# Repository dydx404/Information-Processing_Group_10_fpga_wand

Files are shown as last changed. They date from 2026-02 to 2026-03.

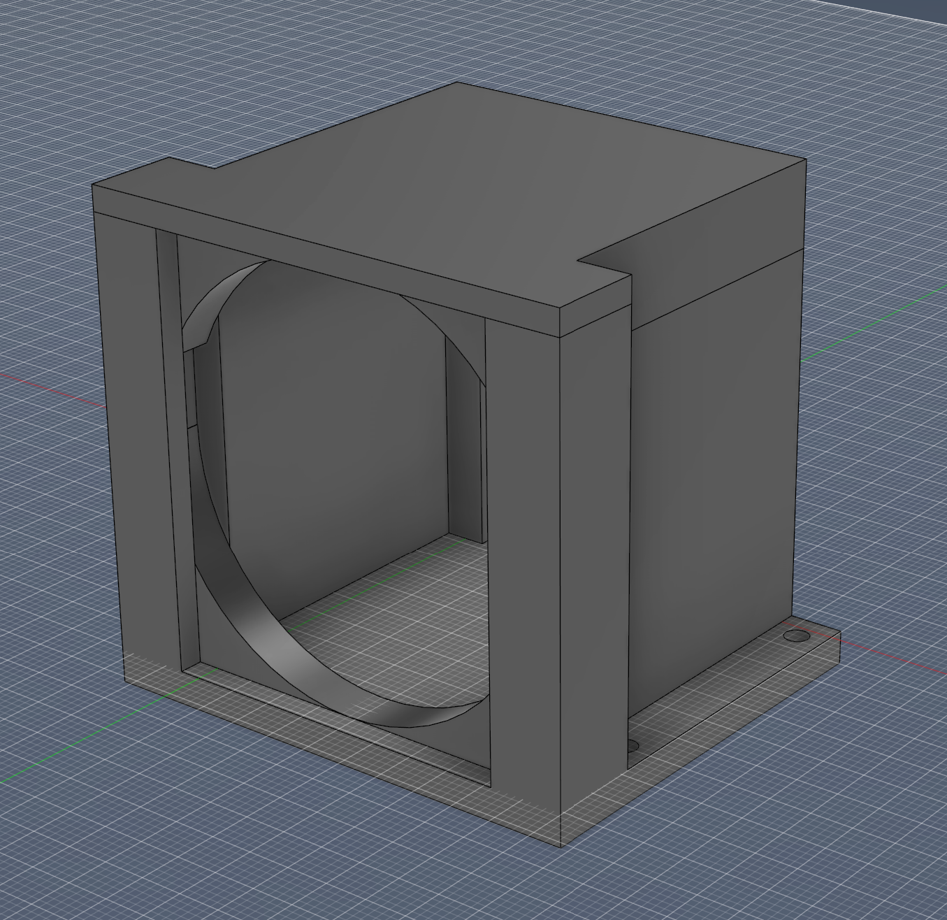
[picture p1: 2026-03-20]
hardware/camera/CamMount/Mount.png

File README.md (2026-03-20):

# FPGA-Wand

FPGA-Wand is a distributed drawing system: a bright LED wand is tracked by a
camera, reduced to centroid data on a PYNQ-Z1, streamed to a cloud service,
and turned into live drawings, scores, leaderboards, and node-control actions.

## Why This Project Is Interesting

This repository is best read as a compact embedded-systems portfolio piece. The
final system combines:

- FPGA + PS + cloud co-design in one working pipeline
- real-time point streaming over UDP
- bidirectional node control over HTTP
- multi-node operation against a shared backend
- live rendering, scoring, persistence, and leaderboards
- a browser-based control and observability console

## Start Here

If you are new to the repo, read these in order:

1. [docs/newcomer_guide.md](docs/newcomer_guide.md)
2. [docs/architecture/overview.md](docs/architecture/overview.md)
3. [FPGA/README.md](FPGA/README.md)
4. [software/README.md](software/README.md)

If you want a quick system explanation first, the project flow is:

```mermaid
flowchart LR
    W[LED Wand Tip] --> C[Camera]
    C --> PS[PYNQ PS Runtime]
    PS --> DMA[AXI DMA]
    DMA --> PL[Centroid PL IP]
    PL --> PS
    PS --> UDP[UDP Point Stream]
    UDP --> WB[Wand Brain on EC2]
    WB --> DB[(SQLite / Persistence)]
    WB --> UI[Live Web Console]
    UI --> HTTP[HTTP Control]
    HTTP --> PS
```

## Repo Map

The repository is organized around the three main implementation areas plus a
shared documentation tree:

- [hardware/](hardware/)
  physical build information for the wand and camera setup
- [FPGA/](FPGA/)
  the adopted PYNQ runtime plus FPGA design artefacts
- [software/](software/)
  the cloud service, protocol definitions, and software-side tools
- [docs/](docs/)
  architecture, validation, runbooks, and archival project notes

For newcomers focused on the technical system, the most important paths are
`FPGA/`, `software/`, and `docs/architecture/`. The `docs/group/` subtree is
kept for archival project-management and report-preparation purposes, but it is not
required to understand the final runtime design.

## Choose A Path

| If you want to understand... | Open this first | Then go here |
| --- | --- | --- |
| The whole system in 10 minutes | [docs/newcomer_guide.md](docs/newcomer_guide.md) | [docs/architecture/overview.md](docs/architecture/overview.md) |
| The FPGA and PYNQ path | [FPGA/README.md](FPGA/README.md) | [FPGA/runtime/ps_pl_flow.md](FPGA/runtime/ps_pl_flow.md) |
| The UDP protocol and point flow | [software/protocol/README.md](software/protocol/README.md) | [software/protocol/protocol/pynq-udp-flow.md](software/protocol/protocol/pynq-udp-flow.md) |
| The Wand Brain backend | [software/cloud/README.md](software/cloud/README.md) | [software/cloud/report/backend_system_report.md](software/cloud/report/backend_system_report.md) |
| The frontend and live console | [software/cloud/frontend/README.md](software/cloud/frontend/README.md) | [software/cloud/frontend/index.html](software/cloud/frontend/index.html) |
| The database model and persistence | [software/cloud/database/README.md](software/cloud/database/README.md) | [software/cloud/database/models.py](software/cloud/database/models.py) |
| How to run the final system | [docs/demo/final_runbook.md](docs/demo/final_runbook.md) | [software/tools/README.md](software/tools/README.md) |
| Validation evidence | [docs/testing/system_validation_report.md](docs/testing/system_validation_report.md) | [software/tools/README.md](software/tools/README.md) |

## What The Final System Does

The final presented system follows this path:

1. A camera observes a bright LED wand tip.
2. The PYNQ PS preprocesses the frame into a binary image.
3. AXI DMA streams the image into a custom centroid IP in the PL.
4. The PS reads centroid statistics, filters them, and maintains stroke logic.
5. The PS sends accepted points to Wand Brain over UDP.
6. Wand Brain reconstructs attempts, renders images, scores them, stores
   finalized results, and serves the live dashboard.
7. The dashboard can also send HTTP control messages back to the PYNQ node.

The architecture deliberately separates:

- UDP as the low-latency point-stream data plane
- HTTP as the control and dashboard plane

## Engineering Highlights

- **Narrow, stable PL design**
  The adopted FPGA path uses a compact centroid-reduction IP rather than a
  heavier full-image pipeline, keeping the PL focused on deterministic
  acceleration.
- **Policy in the PS**
  The PYNQ PS handles filtering, stroke state, node control, and networking, so
  behaviour can be tuned without reworking the PL.
- **Stateful cloud runtime**
  Wand Brain reconstructs live attempts in memory, finalizes them into
  renderable images, scores them, and persists results only when appropriate.
- **Separation of planes**
  UDP is reserved for the point-stream path, while HTTP handles control,
  dashboard status, and operator-facing behaviour.
- **Operator-friendly system**
  The final web console supports monitoring, template selection, node control,
  recent attempts, stroke timing, and leaderboards from one page.

## Local Development

### Run the cloud app

```bash
cd software/cloud
bash start_script.sh --install-deps
```

Then open:

```text
http://127.0.0.1:8000/
```

### Run the PYNQ sender

The board-side demo is:

- [FPGA/runtime/pynq_wand_brain_demo.py](FPGA/runtime/pynq_wand_brain_demo.py)

The main demo can use the configured EC2 address or an overridden
`BRAIN_HOST` value. Each board also needs its own:

- `DEVICE_NUMBER`
- `WAND_ID`

For a more complete run path, see:

- [docs/demo/final_runbook.md](docs/demo/final_runbook.md)

## Source Of Truth

This repo contains both **canonical source** and **runtime-generated data**.
For newcomers, the key distinction is:

- edit and read the source under `hardware/`, `FPGA/`, `software/`, and `docs/`
- do not treat runtime-generated files as the authoritative implementation

Runtime-generated files are intentionally not the source of truth for GitHub:

- `software/cloud/data/fpgawand.sqlite3`
- `software/cloud/data/node_control_state.json`
- `software/cloud/data/outputs/*.png`
- EC2 deployment-only copies such as `cloud/alt_live_console`

The authoritative template source images live in:

- [software/cloud/backend/versions/brain_v2_scoring/data/templates](software/cloud/backend/versions/brain_v2_scoring/data/templates)

## Notes For Contributors

Commit the canonical source under `hardware/`, `FPGA/`, `software/`, and
`docs/`. Avoid committing runtime-only data copied back from local runs or EC2.

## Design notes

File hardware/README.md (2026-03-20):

# Hardware

This directory contains the physical build-side documentation for the project.

## What To Expect Here

This subtree is intentionally lighter than `FPGA/` and `software/`, because the
main engineering depth of the final system sits in the node runtime and cloud
service. Use `hardware/` for physical context:

- what the wand looked like
- how the camera was positioned
- how the physical setup supported reliable tracking

## Subsystems

- [wand/](wand/)
  the physical wand implementation used by the final system.
- [camera/](camera/)
  camera-side mounting, placement, and sensing notes.

## Relationship To The Rest Of The Repo

- [FPGA/](../FPGA/)
  contains the programmable-logic design artefacts and PYNQ runtime code.
- [software/](../software/)
  contains the EC2 cloud service, protocols, and software-side tools.

Use this folder to present what was physically built, rather than the code that
ran on top of it.

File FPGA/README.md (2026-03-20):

# FPGA

This directory contains the FPGA-side implementation of the project.

## If You Open One File First

For most newcomers, start with:

- [runtime/ps_pl_flow.md](runtime/ps_pl_flow.md)

That document explains the final adopted PS/PL signal flow and points back to
the relevant runtime code and Vivado artefacts.

## Main Areas

- [runtime/](runtime/)
  PYNQ-side Python runtime used to bridge the camera/centroid pipeline to the
  Wand Brain cloud service.
- [designs/](designs/)
  archived hardware design artefacts, including the version used in the final
  system and fallback versions.

## PS / PL Architecture

The deployed board design is best understood as a split between:

- the PS as the runtime controller
- the PL as a centroid-statistics accelerator

At a high level, the signal flow is:

1. the PS captures a camera frame
2. the PS preprocesses it into a binary `640 x 480` image
3. the PS sends that image through AXI DMA into the custom centroid IP
4. the PL reduces the frame into `sum_x`, `sum_y`, `count`, `frame_id`, and
   `valid`
5. the PS reads those registers, computes the centroid, applies filtering and
   stroke logic, and sends accepted points to Wand Brain

The control flow is also PS-led:

- the PS polls node control over HTTP
- applies immediate or next-stroke configuration changes
- decides whether tracking is enabled
- decides whether a centroid is good enough to sketch or transmit
- manages the UDP stroke state machine through the runtime bridge

So the PL is intentionally narrow and stable, while the PS holds the policy,
integration, and live control behavior.

For the detailed step-by-step version, see
[runtime/ps_pl_flow.md](runtime/ps_pl_flow.md).

## Newcomer Route

If you are trying to understand the FPGA contribution quickly, read in this
order:

1. [runtime/ps_pl_flow.md](runtime/ps_pl_flow.md)
2. [runtime/pynq_wand_brain_demo.py](runtime/pynq_wand_brain_demo.py)
3. [runtime/pynq_udp_bridge.py](runtime/pynq_udp_bridge.py)
4. [designs/centroid_pipeline/used_version/README.md](designs/centroid_pipeline/used_version/README.md)
5. [designs/centroid_pipeline/used_version/source/frame_centroid.v](designs/centroid_pipeline/used_version/source/frame_centroid.v)

## Suggested Tour

Start here if you want to present the FPGA contribution clearly:

1. [runtime/pynq_wand_brain_demo.py](runtime/pynq_wand_brain_demo.py)
2. [runtime/pynq_udp_bridge.py](runtime/pynq_udp_bridge.py)
3. [runtime/ps_pl_flow.md](runtime/ps_pl_flow.md)
4. [designs/README.md](designs/README.md)
5. [designs/centroid_pipeline/used_version/README.md](designs/centroid_pipeline/used_version/README.md)

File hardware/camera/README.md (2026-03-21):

# Camera Hardware

This folder documents the camera-side hardware used in the FPGA wand tracking
setup. It covers the selected image sensor, lens characteristics, IR filtering
approach, and the mechanical mounting work used to support the sensing node.

## Purpose

The camera subsystem is responsible for reliably observing the tracked wand tip
under motion. The hardware choice emphasizes:

- fast image capture
- reduced motion distortion
- compatibility with IR-assisted tracking
- practical integration with the `PYNQ-Z1`-based node

## Selected Camera

The camera used for the project is the `Arducam B0332`, based on the `OV9281`
global shutter image sensor.

Relevant supporting files in this folder include:

- `B0332_OV9281_Global_Shutter_UVC_Camera_Datasheet.pdf`
- `CamMount/Design_Notes.md`
- the CAD and render files under `CamMount/`

## Sensor Characteristics

Key parameters of the selected camera are:

- `OV9281` monochrome sensor
- global shutter
- `1280 x 800` resolution
- `1 MP` image size
- `3 um x 3 um` pixel size
- `1/4 inch` optical format
- `68 dB` dynamic range
- UVC output support
- `MJPG` and `YUY2` output formats

## Frame Rate

Documented operating modes include:

- `100 fps` at `1280 x 800` in `MJPG`
- `10 fps` at `1280 x 800` in `YUY2`

For this project, the high frame rate is important because fast wand motion
should not be limited by camera capture speed.

## Why This Camera Was Chosen

This camera appears to have been selected for three main reasons:

- `Global shutter` reduces rolling-shutter distortion when the wand moves
  quickly.
- `High frame rate` supports motion tracking with less temporal blur and better
  responsiveness.
- `Monochrome + IR sensitivity` makes the sensor suitable for filtered or
  IR-assisted optical tracking.

Together, these characteristics make the camera a good fit for a tracking
system rather than a general-purpose imaging application.

## Optics And Lens

The current notes indicate the following lens characteristics:

- `2.8 mm` effective focal length
- approximately `70 deg` horizontal field of view
- distortion below `1%`
- `M12 x P0.5 mm` lens mount

This combination suggests a compact wide-angle configuration suitable for
watching the wand workspace from a fixed camera position.

## IR Sensitivity And Filtering

The camera is noted as having no IR cut filter, which means it is sensitive to
near-infrared light. That makes it suitable for use with IR illumination or IR
pass filtering.

This is useful for the project because:

- the tracked target can remain bright in the IR band
- background visible-light clutter can be reduced
- tracking can be made more robust under mixed lighting conditions

The camera mount work in `CamMount/` is intended to hold the IR filter in front
of the lens while minimizing visible light leakage.

## IR Filter Note

The current filter notes record:

- aperture: `49 mm`
- pass band: `85 nm`

These values should be confirmed and expanded later with the exact center
wavelength, supplier part number, and mounting dimensions.

## Mechanical Integration

Mechanical support for the camera is documented in the `CamMount/` folder,
including CAD files and design notes. The mount work appears to focus on:

- placing the filter securely in front of the camera
- reducing stray visible light
- keeping the assembly easy to build and service

This indicates the sensing setup was designed as a real prototype assembly, not
just a camera selection on paper.

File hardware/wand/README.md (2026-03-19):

# Wand Hardware

This folder groups the physical wand implementations and related notes.

## Current Layout

- [current_led_wand/](current_led_wand/)
  the final physical wand direction used for the project demo.

The final integrated system used a simple 3D-printed LED wand as the tracked
optical target.

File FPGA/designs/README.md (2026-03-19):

# FPGA Design Archive

This folder is for the hardware-design side of the PYNQ / FPGA subsystem.

It is intentionally separate from the Python notebook/runtime files in
[../](../) so the repo can present:

- the design currently used in the live system
- a fallback version of that design
- space for a teammate's alternative design work

## Layout

- [centroid_pipeline/](centroid_pipeline/)
  current centroid-based design family used by the live system.
- [teammate_design/](teammate_design/)
  reserved slot for a second design track.

## Per-Version Conventions

Each version folder is split into:

- `source/`
  HDL, block-design Tcl, IP configuration exports, or any source artefacts
  needed to recreate the design.
- `constraints/`
  XDC constraints and board-specific pin/timing files.
- `export/`
  generated handoff artefacts you intentionally want to keep, such as `.bit`,
  `.hwh`, `.xsa`, or packaged deliverables.
- `docs/`
  design notes, architecture summaries, and implementation rationale.
- `reports/`
  timing, utilization, and synthesis/implementation reports worth preserving.
- `images/`
  screenshots, block diagrams, or presentation visuals.

## Suggested Usage

- Put the design you actually demonstrated into `centroid_pipeline/used_version`.
- Put the simpler or safer backup build into `centroid_pipeline/fallback_version`.
- Let your teammate populate `teammate_design/` with another architecture or
  implementation approach.

If you later want more specific names, you can rename these top-level design
folders without changing the rest of the structure.

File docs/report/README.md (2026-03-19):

# Report Notes

This folder is reserved for report-specific material that is separate from the
runtime code and operator documentation.

For the actual system architecture and interfaces, prefer:

- [../architecture/overview.md](../architecture/overview.md)
- [../../README.md](../../README.md)

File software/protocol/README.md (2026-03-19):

# Protocols

This directory contains the explicit interface contracts used across the
project.

## Current Important Specs

- [protocol/pynq-udp-brian-v1.md](protocol/pynq-udp-brian-v1.md)
  defines the fixed-size UDP point-stream packet from PYNQ to Wand Brain.
- [protocol/pynq-udp-flow.md](protocol/pynq-udp-flow.md)
  explains how the PYNQ sender, UDP receiver, parser, and backend state machine
  use that packet format end to end.
- [protocol/brain-web_api.md](protocol/brain-web_api.md)
  indexes the HTTP API families used by the frontend, control plane, scoring,
  leaderboard, and database views.
- [protocol/brain_api/README.md](protocol/brain_api/README.md)
  expands the Brain HTTP APIs into separate detailed guides by feature area.

## Design Principle

The protocol docs are the contract boundary between subsystems. The packet
format should remain stable unless all affected owners agree to the change.

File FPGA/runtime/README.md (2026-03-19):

# PYNQ Runtime

Use [pynq_udp_bridge.py](pynq_udp_bridge.py) to send centroid points from a
PYNQ notebook or script to Wand Brain.

## Repository Layout

- runtime integration code stays directly in [./](.)
- hardware design artefacts live under [../designs/](../designs/)

That split keeps the repo easier to present:

- software/runtime logic in one place
- Vivado/export/design evidence in another

## What It Does

- keeps the camera + DMA + MMIO centroid pipeline unchanged
- performs an HTTP preflight check against Wand Brain
- sends one `wb-point-v1` UDP packet per valid centroid point
- starts a new stroke on the first valid point after idle
- sends one explicit `STROKE_END` packet after a short no-blob gap

## Deep Dive

For the actual deployed signal path and control decisions, see
[ps_pl_flow.md](ps_pl_flow.md). That document walks through:

- camera frame preprocessing on the PS
- DMA transfer into the custom centroid IP
- register readback from the PL
- fresh-result detection using `frame_id`
- UDP stroke generation
- server-driven node control and acknowledgements

## Minimal Notebook Pattern

```python
import sys
sys.path.append("/home/xilinx/Information-Processing_Group_10_fpga_wand")

from FPGA.runtime.pynq_udp_bridge import WandBrainConfig, WandBrainUdpBridge

bridge = WandBrainUdpBridge(
    WandBrainConfig(
        brain_host="13.51.156.87",
        brain_udp_port=41000,
        brain_api_port=8000,
        device_number=1,
        wand_id=1,
        starting_stroke_id=1,
        gap_timeout_ms=220,
        mirror_x=True,
    )
)

print(bridge.preflight_check())
```

## Notes

- Set `brain_host` to the current EC2 public IP. In the main demo script this
  can be overridden with the `BRAIN_HOST` environment variable.
- `timestamp_ms=None` means the bridge uses local monotonic milliseconds.
- `mirror_x=True` makes backend rendering match the mirrored local sketch view.
- The bridge sends explicit `STROKE_END`, which is compatible with both older
  and newer Wand Brain builds.
- For the centroid notebook demo, prefer `MIN_COUNT_TO_ACCEPT >= 4` and
  `VALID_STREAK_REQUIRED >= 2` to suppress single-pixel flicker and one-frame
  false starts.

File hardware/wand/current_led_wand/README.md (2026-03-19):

# Current LED Wand

This folder is reserved for the final wand hardware that was actually used in
the project demonstration.

Recommended contents:

- photos of the 3D-printed wand
- LED placement notes
- simple wiring notes
- any assembly drawings or STL references
- practical observations from testing

Important context:

- this final wand was used as a simple bright tracked tip for the
  camera/FPGA pipeline
- the repo’s active implementation does not require a separate embedded wand
  firmware path

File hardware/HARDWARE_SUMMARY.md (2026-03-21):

# Hardware Report

## 1. Introduction

This report summarizes the hardware work documented under
`fpga_wand/hardware/`. The purpose of this part of the repository is to record
the physical prototype used in the FPGA wand tracking system, including the
camera subsystem, the tracked wand, the node-level hardware arrangement, and
the supporting bill of materials.

The contents of this folder show that the project progressed beyond algorithm
and FPGA development into a working physical prototype with selected hardware,
custom mechanical parts, and a defined sensing configuration.

## 2. Hardware System Overview

The documented hardware is centered on a `PYNQ-Z1`-based node used for image
capture and system integration. At the top level, the hardware folder includes
general notes and a node layout diagram that describe how the main components
fit together.

The single-node layout indicates the following structure:

- a camera connected through a USB hub
- a WiFi adapter connected through the same USB hub
- the hub connected to the `PYNQ-Z1`
- the `PYNQ-Z1` connected to a host computer for power and Ethernet

This arrangement suggests a practical prototype architecture in which the FPGA
board acts as the central processing node while the camera and communications
hardware are attached as external peripherals.

## 3. Camera Subsystem

The camera subsystem is the most fully documented part of the hardware
directory. The current records identify the selected camera as the `Arducam
B0332`, based on the `OV9281` image sensor.

The documented sensor characteristics include:

- monochrome operation
- global shutter imaging
- `1280 x 800` resolution
- `1 MP` image size
- support for `MJPG` and `YUY2` output
- high-speed operation up to `100 fps` in `MJPG`

The camera choice appears to have been driven by the needs of fast optical
tracking. In particular, the use of a global shutter reduces image distortion
during rapid wand motion, while the high frame rate helps ensure that the
camera is not the main bottleneck in the tracking pipeline.

The optics notes further indicate a `2.8 mm` lens with an approximately
`70 deg` horizontal field of view and an `M12 x P0.5 mm` lens mount. The camera
is also described as having no IR cut filter, making it suitable for
near-infrared-sensitive operation.

Taken together, these details show that the selected camera was well matched to
the requirements of a motion-tracking system rather than a general-purpose
imaging task.

## 4. IR Filtering And Camera Mount Design

The repository contains dedicated camera mount assets under
`hardware/camera/CamMount/`, including CAD files, a rendered image, and a set
of design notes. These files provide strong evidence that the optical setup was
mechanically developed rather than left as a loose concept.

The documented design intent of the mount is to:

- position the IR filter directly in front of the camera
- reduce visible light leakage into the optical path
- keep the assembly easy to install, remove, and adjust
- support repeatable positioning during prototype testing

This mount design is important because the effectiveness of IR-assisted
tracking depends not only on the sensor itself, but also on how well the filter
is integrated into the physical camera assembly. The available documentation
shows that the project considered both optical performance and practical
assembly during this stage of development.

## 5. Wand Hardware

The hardware folder also documents the tracked wand used in the final project
direction. The available files include a wand model, a rendered image, and a
simple schematic.

These materials indicate that the final tracked target was a custom handheld
LED wand rather than a complex embedded device. The wand appears to include:

- a long narrow visible structure suitable for tracking
- a custom enclosure
- a pushbutton integrated into the handle
- a simple electrical arrangement using a `7.4V` supply, a red LED, and an IR
  LED

This suggests that the wand was intended to act as a bright and easily detected
optical target for the camera/FPGA pipeline, while keeping the hardware simple
and practical for demonstration purposes.

## 6. Bill Of Materials

The top-level bill of materials provides a first-pass procurement view of the
system. It includes the major camera, compute, optical, power, and enclosure
items needed to assemble the prototype.

The BOM covers:

- cameras and lenses
- USB and connectivity hardware
- `PYNQ-Z1` boards
- WiFi adapters
- LEDs and switches
- battery-related items
- custom 3D-printed mechanical parts

This is a useful foundation for prototype assembly, although it still reads as
a draft document rather than a fully finalized production BOM. Some entries are
generic, some are marked as optional, and a few text encoding issues remain in
the file.

## 7. Assessment Of Current Progress

Based on the files currently present in `hardware/`, the core hardware concept
for the project has already been established. The repository shows evidence of:

- camera selection based on tracking requirements
- definition of the node-level hardware arrangement
- mechanical design work for camera filtering and mounting
- development of a dedicated tracked wand form factor
- preparation of a bill of materials for the build

This means the hardware portion of the project is already beyond the idea stage.
The available documentation points to a real prototype effort with concrete
design decisions and supporting artifacts.

## 8. Remaining Gaps

Although the main hardware direction is clearly documented, the folder still
has some areas that would benefit from further reporting and cleanup.

The most obvious remaining gaps are:

- finalized supplier-ready BOM entries
- clearer assembly instructions
- dimensions and tolerances for the printed parts
- print settings and recommended materials
- fuller wand-side written documentation
- photos of the assembled prototype
- final placement, calibration, and validation notes for the camera setup

These are primarily documentation and refinement tasks rather than missing
fundamental hardware design work.

## 9. Conclusion

The `fpga_wand/hardware/` subtree documents a credible physical prototype for
the FPGA wand tracking project. The strongest elements are the selected global
shutter camera, the IR-aware camera mount design, the custom LED wand model,
and the single-node architecture built around the `PYNQ-Z1`.

In summary, the repository already captures the essential hardware design of the
system. The main next step is to improve completeness and presentation by
expanding assembly details, cleaning the BOM, and recording more evidence from
the final physical build.

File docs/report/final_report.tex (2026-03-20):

\documentclass[10pt,a4paper]{article}

\usepackage[margin=1.6cm]{geometry}
\usepackage[T1]{fontenc}
\usepackage[utf8]{inputenc}
\usepackage{lmodern}
\usepackage{microtype}
\usepackage{graphicx}
\usepackage{booktabs}
\usepackage{tabularx}
\usepackage{array}
\usepackage{enumitem}
\usepackage{xcolor}
\usepackage{hyperref}
\usepackage{tikz}
\usetikzlibrary{arrows.meta,positioning,shapes.geometric}

\hypersetup{
  colorlinks=true,
  linkcolor=black,
  urlcolor=blue!50!black
}

\setlength{\parindent}{0pt}
\setlength{\parskip}{0.45em}
\setlist[itemize]{leftmargin=*, itemsep=0.2em, topsep=0.2em}
\setlist[enumerate]{leftmargin=*, itemsep=0.2em, topsep=0.2em}

\title{\vspace{-1.2em}\textbf{FPGA Wand: A Multi-Node Interactive Drawing System with Local FPGA Processing and Cloud Coordination}\vspace{-0.8em}}
\author{[Author Name]}
\date{}

\begin{document}
\maketitle
\vspace{-1.4em}

\section{Purpose of the System}

The aim of this project was to build a distributed interactive system in which
multiple FPGA SoC nodes perform meaningful local processing, exchange compact
events with a cloud service, and can also be influenced by server-side control.
The final implemented system is an interactive ``wand drawing'' platform built
around PYNQ boards, a camera-based local processing pipeline, and a cloud
service called \emph{Wand Brain}. Each node observes a bright LED wand through a
camera, reduces each frame locally to a centroid-like point, and transmits this
point stream to the cloud as stroke events. The cloud reconstructs attempts,
renders them live in a browser dashboard, scores finalized strokes against
target templates, maintains leaderboards, and sends control settings back to
the nodes.

This final system was chosen because it satisfies all minimum functional
requirements while remaining technically rich. It demonstrates local processing
on the FPGA SoC device, server-side event processing, bidirectional
communication between node and server, and concurrent operation of at least two
nodes. The design also leaves clear space for extension, including alternative
templates, richer scoring, and more advanced node-side vision.

\section{Overall Architecture}

\begin{figure}[t]
\centering
\begin{tikzpicture}[
  node distance=0.85cm and 0.65cm,
  box/.style={draw, rounded corners, align=center, minimum width=2.4cm, minimum height=0.9cm, fill=blue!4},
  smallbox/.style={draw, rounded corners, align=center, minimum width=2.15cm, minimum height=0.8cm, fill=green!4},
  cloudbox/.style={draw, rounded corners, align=center, minimum width=2.65cm, minimum height=0.95cm, fill=orange!6},
  line/.style={-{Latex[length=2mm]}, thick}
]
\node[box] (camera) {USB Camera\\BGR Frames};
\node[box, right=of camera] (ps) {PYNQ PS\\OpenCV preprocessing\\UDP/HTTP logic};
\node[smallbox, below=of ps] (dma) {AXI DMA};
\node[smallbox, left=of dma] (pl) {Custom PL IP\\frame\_centroid\_axi};
\node[cloudbox, right=of ps, xshift=1.0cm] (brain) {EC2 ``Wand Brain''\\UDP ingest, render, score, persist};
\node[cloudbox, below=of brain] (db) {SQLite history\\leaderboards};
\node[box, above=of brain] (web) {Browser dashboard\\live view and control};

\draw[line] (camera) -- node[above, font=\scriptsize] {frame capture} (ps);
\draw[line] (ps) -- node[right, font=\scriptsize] {binary frame buffer} (dma);
\draw[line] (dma) -- node[below, font=\scriptsize] {AXI stream} (pl);
\draw[line] (pl) -- node[left, font=\scriptsize] {AXI-Lite stats} (ps);
\draw[line] (ps) -- node[above, font=\scriptsize] {24-byte UDP point packets} (brain);
\draw[line] (brain) -- node[right, font=\scriptsize] {finalized attempts} (db);
\draw[line] (web) -- node[right, font=\scriptsize] {HTTP polling} (brain);
\draw[line] (brain.west) to[bend right=18] node[below, font=\scriptsize] {HTTP node control} (ps.east);
\end{tikzpicture}
\caption{End-to-end architecture of the final system. The fast data plane uses
UDP point events from the node to the cloud, while the control plane uses HTTP
from the cloud back to the node.}
\label{fig:system-architecture}
\end{figure}

Figure~\ref{fig:system-architecture} shows the split between the local node and
the cloud service. The local node combines the programmable logic (PL) and the
processing system (PS) of the PYNQ board. The PS is responsible for camera
capture, grayscale conversion, resizing to $640 \times 480$, thresholding,
runtime filtering, stroke management, and networking. The PL accelerates the
repetitive per-pixel reduction stage by scanning the thresholded binary frame
and exposing compact image statistics instead of a full processed image.

\subsection*{Node-side PS/PL partition}

The adopted FPGA design consists of a custom AXI-stream IP,
\texttt{frame\_centroid\_axi}, attached to an AXI DMA engine and accessed by the
PS through AXI-Lite. After the PS thresholds a frame, it writes the binary
image into a DMA buffer in memory. The DMA then streams the image into the PL,
where four pixels are processed per 32-bit beat. The custom IP accumulates:
\begin{itemize}
  \item the horizontal coordinate sum $\sum x$,
  \item the vertical coordinate sum $\sum y$,
  \item the foreground-pixel count,
  \item a frame identifier, and
  \item a valid bit.
\end{itemize}
The PS reads these registers through MMIO and computes the centroid using
$c_x=\sum x / \mathrm{count}$ and $c_y=\sum y / \mathrm{count}$. This is a
deliberate partition: the PL performs the regular streaming arithmetic, while
the PS keeps the flexible logic in software, including filtering, control
handling, sketch rendering, and networking.

\subsection*{Cloud-side runtime}

The cloud service is a FastAPI application deployed on EC2. It is divided into
two layers. The base runtime receives UDP packets on port 41000, validates and
parses them into structured point events, groups them into live attempts, and
renders both live and finalized drawings. A wrapper layer adds persistence,
template selection, node control, recent-attempt views, leaderboards, and the
HTML dashboard. The server also exposes health, template, and debugging routes
over HTTP on port 8000.

The browser frontend is a deliberately simple single-page console. It polls the
backend rather than using WebSockets, which made the system easier to debug and
deploy during rapid iteration. Live frame polling is configured at 180\,ms,
selected-wand status at 500\,ms, and health/leaderboard polling at slower
intervals. This produces a responsive operator view while keeping the client
logic lightweight.

\section{Performance Metrics and Their Rationale}

Because the project is an interactive distributed system, its performance
cannot be described by a single number. The most relevant metrics are the ones
that determine whether a user can draw reliably, whether the cloud reconstructs
the intended stroke, and whether the FPGA acceleration is justified.

\begin{table}[t]
\centering
\small
\begin{tabularx}{\linewidth}{>{\raggedright\arraybackslash}p{2.8cm} >{\raggedright\arraybackslash}p{4.1cm} X}
\toprule
\textbf{Metric} & \textbf{Why it matters} & \textbf{How it is evidenced in this project} \\
\midrule
End-to-end stroke correctness & The system must turn a physical wand motion into the correct live and finalized attempt. & Verified through live rendering, finalized PNG endpoints, scoring output, and synthetic plus live-board tests. \\
Interaction responsiveness & Drawing is only usable if the system responds quickly enough for human feedback. & Compact 24-byte point packets, local point gating on the node, and a responsive polling dashboard were used to reduce perceived delay. \\
Multi-node isolation & Minimum requirements demand concurrent receive/transmit from at least two nodes. & \texttt{device\_number} and \texttt{wand\_id} are carried through transport, backend state, and UI; two-node live validation was completed. \\
Control-plane correctness & The server must be able to affect local processing on the nodes. & HTTP control and acknowledgement routes were added, with runtime changes such as \texttt{enabled}, \texttt{armed}, thresholds, and recalibration. \\
FPGA efficiency & The local hardware must provide useful acceleration without becoming too large or fragile to integrate. & The final PL design performs only the image-reduction stage in hardware, streams four pixels per beat, and met timing closure. \\
\bottomrule
\end{tabularx}
\caption{Chosen performance metrics for the implemented system.}
\label{tab:metrics}
\end{table}

The system was intentionally evaluated in terms of correctness, responsiveness,
and deployability rather than headline throughput alone. For example, the UDP
protocol sends one point per 24-byte datagram rather than a frame or a large
batch. This keeps the transport lightweight and suits interactive drawing, for
which occasional packet loss is less harmful than retransmission delay. By the
same logic, the frontend uses frequent polling only where it most affects user
feedback, such as live frame refresh, while slower-changing views use longer
poll intervals.

\section{Design Decisions and Evaluation}

\subsection*{Hardware/software split}

One of the most important design decisions was to avoid placing the entire
vision pipeline into the PL. Instead, the PL implements the streaming reduction
stage only, while the PS performs thresholding, centroid division, validity
rules, and network communication. This trades maximum hardware throughput for
integration reliability and flexibility. In practice, it was a good compromise:
the custom IP still accelerates the repetitive per-pixel work, but changes to
tracking behaviour, stroke rules, and cloud interaction remain easy to make in
software.

\subsection*{UDP data plane, HTTP control plane}

The system uses two protocols with distinct roles. The data plane uses the
\texttt{wb-point-v1} UDP packet format, where each datagram contains one point,
stroke flags, node identity, and a timestamp. This design keeps latency low and
allows explicit stroke lifecycle events such as \texttt{STROKE\_START} and
\texttt{STROKE\_END}. In contrast, the control plane uses HTTP because control
messages need versioning, readability, and easy debugging. This made it
straightforward to add node control, health checks, and acknowledgements
without destabilizing the point-stream path.

\subsection*{In-memory live state with persisted finalized history}

The cloud keeps active strokes in memory and only persists attempts once they
are finalized. This was another deliberate trade-off. It avoids database
overhead on every incoming point and allows the backend to update live images
very cheaply. The disadvantage is that active in-memory state is lost if the
server restarts. For the current project stage this was acceptable, because
historical scoring, recent attempts, and leaderboards all depend on finalized
rather than partially complete strokes.

\subsection*{Single-page dashboard}

The dashboard is implemented as a single HTML page with embedded JavaScript.
This choice reduced framework overhead and kept the live demo easy to deploy on
EC2. It also supported rapid additions such as node control, stroke timers, and
leaderboards. The downside is that the page relies on polling rather than true
server push, so it is better suited to this lab-scale console than to a large
production deployment. For the project brief, however, the simplicity and
clarity of this approach were strong advantages.

\section{Testing Approach and Validation}

\begin{figure}[t]
\centering
\begin{tikzpicture}[
  node distance=0.55cm and 0.6cm,
  flowstep/.style={draw, rounded corners, align=center, minimum width=2.6cm, minimum height=0.85cm, fill=gray!8},
  flow/.style={-{Latex[length=2mm]}, thick}
]
\node[flowstep] (cloud) {Cloud sanity check\\health, templates, dashboard};
\node[flowstep, right=of cloud] (udp) {UDP connectivity\\synthetic stroke injection};
\node[flowstep, right=of udp] (smoke) {Smoke test\\render + finalize paths};
\node[flowstep, below=of udp] (board) {PYNQ validation\\camera, DMA, MMIO, control};
\node[flowstep, left=of board] (multi) {Two-node test\\simultaneous draw paths};
\node[flowstep, right=of board] (ui) {Frontend regression\\score, timer, leaderboard};

\draw[flow] (cloud) -- (udp);
\draw[flow] (udp) -- (smoke);
\draw[flow] (smoke) -- (ui);
\draw[flow] (smoke) -- (board);
\draw[flow] (board) -- (multi);
\draw[flow] (board) -- (ui);
\end{tikzpicture}
\caption{Testing flow used to move from isolated service checks to full
integrated multi-node validation.}
\label{fig:test-flow}
\end{figure}

The testing strategy combined tool-based validation with live integrated
demonstrations. Figure~\ref{fig:test-flow} summarizes the progression from
isolated checks to full-system tests.

At the cloud-only level, the backend was first validated through a health
check, template enumeration, and dashboard loading. Lightweight Python tools
were then used to inject synthetic UDP strokes and verify that the latest
attempt, live image, and finalized image endpoints behaved correctly. A further
smoke test exercised the full finalize-and-render path without requiring the
camera or FPGA board, which made regression testing much faster.

Board-level validation focused on the FPGA SoC runtime. This included camera
bring-up, repeated DMA/MMIO frame updates, correct extraction of centroid
statistics, and successful communication with the cloud over both UDP and HTTP.
The control-plane path was checked by observing control acknowledgements under
the node-control API. These tests confirmed that the server could affect local
node behaviour by enabling or disabling tracking, changing thresholds and gap
timeouts, and triggering recalibration.

The final integration stage used real hardware, the actual FPGA design, the EC2
deployment, and the browser dashboard. Both one-node and two-node sessions were
completed. The following final-system behaviours were validated:
\begin{itemize}
  \item correct UDP receive and parse on the cloud;
  \item live stroke plotting during active drawing;
  \item finalized-attempt rendering and template scoring;
  \item recent-attempt and database-backed history updates;
  \item HTML-based node control and acknowledgement;
  \item leaderboard promotion and champion-name claim logic; and
  \item simultaneous receive/transmit from two nodes.
\end{itemize}

This staged approach was particularly important because several integration
issues appeared only during full-system testing. Examples included camera
bring-up fragility on the PYNQ board, the need to separate backend-owned
\texttt{attempt\_id} values from incoming UDP \texttt{stroke\_id} values, and
ordering the recent-attempt list by finalization time rather than creation time.
Each issue was addressed without changing the overall architecture, which is a
useful indication that the design boundaries were sensible.

\section{Device Resources and Hardware Implementation}

The adopted FPGA implementation is intentionally compact. Rather than storing
frames or implementing a full image-processing graph in hardware, the custom PL
block performs only what is both repetitive and structurally regular: scanning
the thresholded image stream and accumulating foreground statistics. This has
several resource-related advantages:
\begin{itemize}
  \item no connected-component analysis in hardware;
  \item no hardware frame buffer for the processed image;
  \item no hardware division for centroid calculation;
  \item a narrow AXI-Lite register interface for result readback; and
  \item reuse of the PS for all policy, filtering, and network logic.
\end{itemize}

This means the PL resource footprint is dominated by simple counters,
accumulators, stream handling, and interface logic rather than by large memory
structures or complex arithmetic. Architecturally, this is a strong fit for the
project: the node still benefits from genuine hardware acceleration, but the
design remains understandable and practical to debug.

The archived implementation evidence includes a timing summary rather than a
complete post-implementation utilization table. Even so, the available timing
result is encouraging: the implemented design closed timing with setup worst
negative slack of 11.636\,ns, hold slack of 0.045\,ns, pulse-width slack of
8.750\,ns, and zero failing endpoints. This confirms that the final chosen PL
path was not only functionally useful but also straightforward to implement
reliably on the target platform.

\section{Conclusion}

The final system demonstrates a complete multi-node FPGA-to-cloud interactive
application rather than a collection of isolated components. Each node performs
local camera processing on the PYNQ board, the PL accelerates the image
reduction stage, the PS packages and transmits stroke events over UDP, the
cloud reconstructs and scores attempts, and the server can also influence the
node through HTTP control. The system therefore satisfies the key coursework
requirements while also providing additional functionality such as live plotting,
template-based scoring, stroke timers, and leaderboards.

From an engineering perspective, the most successful design choice was the
clear separation of responsibilities: regular streaming arithmetic in the PL,
flexible policy and networking in the PS, low-latency event transport over UDP,
and coordination, persistence, and presentation in the cloud service. The main
remaining limitations are also clear. The current centroid-based tracker cannot
separate multiple bright blobs, active live state is not preserved across a
server restart, and the dashboard relies on polling rather than push updates.
These limitations provide a direct roadmap for future work, but they do not
prevent the present system from operating as a coherent and demonstrably working
multi-node information-processing platform.

\end{document}

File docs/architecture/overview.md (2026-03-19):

# Architecture Overview

The current system is best understood as two coordinated planes:

- a UDP point-stream data plane
- an HTTP control and dashboard plane

## Data Plane

1. PYNQ captures camera frames.
2. The FPGA design computes centroid statistics for bright pixels.
3. PS software filters those results and emits one `wb-point-v1` UDP packet per
   valid point.
4. The cloud backend parses packets and reconstructs live strokes in memory.
5. Finalized strokes are rasterized, scored, and persisted.

## Control Plane

The same PYNQ node also polls the cloud service over HTTP for revisioned control
state:

- `enabled`
- `armed`
- `tx_enabled`
- `mode`
- threshold and stroke-profile settings
- one-shot commands such as `clear_sketch` and `recalibrate`

The browser dashboard also uses HTTP polling for:

- health
- live wand status
- latest attempt
- score
- node control
- recent attempts
- leaderboards

## Responsibility Split

### PL

- centroid-style hardware acceleration

### PS

- camera handling
- preprocessing
- DMA and MMIO orchestration
- validity decisions
- local sketching
- UDP sending
- HTTP control polling and ack

### Cloud Runtime

- UDP receive and parse
- in-memory live attempt state
- rasterization
- scoring
- persistence on finalize
- frontend APIs

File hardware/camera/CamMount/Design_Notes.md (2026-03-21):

# Camera Mount Design Notes

## Purpose

This mount is intended to position the IR filter directly in front of the camera
while supporting a clean and practical mechanical assembly for the tracking
setup.

## Design Goals

The mount was designed to:

- hold the IR filter securely in front of the camera lens
- minimize visible light leakage around the filter and camera opening
- keep the optical path as unobstructed as possible
- remain easy to assemble, remove, and re-fit during testing
- provide a stable structure for repeatable camera positioning

## Optical Intent

The main optical purpose of the mount is to support IR-based sensing by placing
the filter in a controlled position ahead of the camera. A close-fitting
mechanical enclosure helps reduce stray visible light entering from the sides,
which improves the usefulness of the filter in mixed lighting conditions.

## Mechanical Intent

The mount is intended to be simple rather than highly complex. It should:

- support the filter without excessive movement
- allow straightforward access during maintenance or part replacement
- be practical to print and handle as a prototype part
- avoid making camera installation unnecessarily difficult

## Assembly Considerations

During assembly, the mount should make it easy to:

- place the filter in the correct position
- align the filter and camera opening
- remove the filter or mount when adjustments are needed
- reassemble the unit without damaging the printed part

## Prototype Notes

This design prioritize rapid prototyping and iterative testing over
full enclosure sealing. The key balance is between optical shielding and ease of
use: the mount should block as much unwanted visible light as possible while
still being convenient to assemble and disassemble.

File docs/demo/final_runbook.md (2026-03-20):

# Final Runbook

This runbook is the shortest practical path for launching and checking the
final adopted FPGA-Wand system.

It is written for someone who wants to run the project, verify that the main
data path works, and understand what “healthy” looks like.

---

## Final-System Components

The final system has two active runtime sides:

1. **Cloud side**
   Wand Brain on EC2 or a local machine
2. **Node side**
   PYNQ runtime on one or more boards

The basic interaction is:

- PYNQ sends UDP point packets to Wand Brain
- Wand Brain serves the live dashboard over HTTP
- PYNQ polls HTTP control state from Wand Brain

---

## Default Ports

- `8000/tcp`
  live console and HTTP APIs
- `41000/udp`
  point-stream ingest from PYNQ nodes

---

## 1. Start The Cloud Side

From the repository root:

```bash
cd software/cloud
bash start_script.sh --install-deps
```

Expected result:

- the FastAPI app starts successfully
- the dashboard becomes available at `http://127.0.0.1:8000/`

Basic health check:

```bash
curl http://127.0.0.1:8000/api/v1/health
```

Expected response shape:

```json
{"ok": true, "...": "..."}
```

---

## 2. Prepare The PYNQ Node

The main node runtime is:

- [../../FPGA/runtime/pynq_wand_brain_demo.py](../../FPGA/runtime/pynq_wand_brain_demo.py)

Before running it, confirm:

- the correct `.bit` / `.hwh` files are available on the board
- the camera is connected and readable
- `BRAIN_HOST` points to the correct Wand Brain host
- each board has a unique:
  - `DEVICE_NUMBER`
  - `WAND_ID`

If needed, the cloud host can be overridden through `BRAIN_HOST`.

---

## 3. Run The PYNQ Node

Launch the board-side runtime from the PYNQ environment using the current
configured demo path.

What healthy startup looks like:

- overlay loads successfully
- DMA IP is found
- centroid IP is found
- camera opens successfully
- Wand Brain health check succeeds

The most useful startup stages are:

- `Loading overlay...`
- `Allocating DMA buffer...`
- `Opening camera...`
- `Opening Wand-Brain bridge...`
- `Checking Wand-Brain health...`

If startup stops consistently at one of those steps, the fault is usually local
to that subsystem.

---

## 4. Check The Dashboard

Open:

```text
http://127.0.0.1:8000/
```

Healthy behaviour:

- wand entries appear in the UI
- the live drawing area updates while the wand is active
- finalized attempts appear after stroke completion
- scores and templates update after finalization
- node control state is visible if the node-control-enabled runtime is in use

---

## 5. Useful Verification Paths

### Health only

```bash
curl http://127.0.0.1:8000/api/v1/health
```

### Live wand list

```bash
curl http://127.0.0.1:8000/api/v1/wands
```

### Node connectivity and UDP check

```bash
python3 software/tools/wb_connection_check.py --host 127.0.0.1 --udp-port 41000 --api-port 8000
```

### End-to-end smoke test

```bash
python3 software/tools/full_system_smoke_test.py --host 127.0.0.1 --udp-port 41000 --api-port 8000
```

---

## 6. Healthy-System Checklist

The system is behaving correctly if the following are true:

- `api/v1/health` returns success
- the PYNQ node can complete startup
- UDP points appear as live attempts
- finalized attempts render to images
- the dashboard updates without manual refresh
- control changes can be observed on node-aware runtimes

---

## 7. Common Failure Points

### Cloud starts, but no live drawing appears

Check:

- PYNQ `BRAIN_HOST`
- UDP port `41000`
- whether the node is actually sending valid points

### Overlay loads, but node does not move past camera startup

Check:

- camera device availability
- camera index
- board-side OpenCV / capture state

### Packets appear, but the wrong node identity shows up

Check:

- `DEVICE_NUMBER`
- `WAND_ID`
- whether another board is still transmitting

### Dashboard loads, but node control does not apply

Check:

- whether the running node runtime includes the HTTP control polling logic
- whether the selected board is using the current `pynq_udp_bridge.py`

---

## 8. Best Supporting Files

If you need to go one level deeper after this runbook, open:

- [../../FPGA/runtime/ps_pl_flow.md](../../FPGA/runtime/ps_pl_flow.md)
- [../../software/protocol/protocol/pynq-udp-flow.md](../../software/protocol/protocol/pynq-udp-flow.md)
- [../../software/cloud/report/backend_system_report.md](../../software/cloud/report/backend_system_report.md)

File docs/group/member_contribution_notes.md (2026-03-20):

# Member Contribution Notes

This document collects **report-safe, evidence-based attribution notes** for
individual members.

It is intended to support the final report by separating:

- planned responsibility
- confirmed contribution to the **final presented model**
- exploratory or non-adopted work
- wording that remains professional, conservative, and defensible

These notes should be updated only when there is a clear evidence basis for the
claim being added.

---

## Yi

### Planned responsibility

Yi appears in the project history both as the early organiser of the repository
and planning structure and as a technical contributor across the project’s
development.

The early branch and documentation history supports planned responsibility in
at least three areas:

- initial project setup and documentation
- early wand-side exploration
- system-level coordination and integration planning

For report-preparation purposes, the `develop` branch is being treated as Yi’s
delivery branch, following direct project clarification.

### Confirmed evidence

The current `develop` branch contains the adopted project structure and the
final documented implementation path. Its visible history also shows sustained
Yi-authored commits across:

- repository setup
- working agreement and milestone documents
- protocol and API definitions
- WandBrain MVP and later backend evolution
- testing scripts
- final repo restructuring and documentation of the delivered system

The authorship history on `develop` is dominated by Yi-associated identities:

- `Yi DONG <yd1723@ic.ac.uk>`
- `dydx404 <yd1723@ic.ac.uk>`
- `dydx <yd1723@ic.ac.uk>`

This makes it reasonable, for report purposes, to treat `develop` as the main
evidence base for Yi’s implemented contribution to the final adopted system.

### Relation to the final presented model

Under that evidence rule, the final presented model shows Yi as the primary
implemented owner of major parts of the adopted system, including:

- the adopted fallback FPGA PL design path
  - [`frame_centroid.v`](/home/bensonyi/FPGA_wand/Information-Processing_Group_10_fpga_wand/FPGA/designs/centroid_pipeline/used_version/source/frame_centroid.v)
  - [`design_1_wrapper.tcl`](/home/bensonyi/FPGA_wand/Information-Processing_Group_10_fpga_wand/FPGA/designs/centroid_pipeline/used_version/source/design_1_wrapper.tcl)
- the node-side PS/runtime and UDP sender path
  - [`pynq_wand_brain_demo.py`](/home/bensonyi/FPGA_wand/Information-Processing_Group_10_fpga_wand/FPGA/runtime/pynq_wand_brain_demo.py)
  - [`pynq_udp_bridge.py`](/home/bensonyi/FPGA_wand/Information-Processing_Group_10_fpga_wand/FPGA/runtime/pynq_udp_bridge.py)
- the final adopted WandBrain ingest/runtime path
  - [`server.py`](/home/bensonyi/FPGA_wand/Information-Processing_Group_10_fpga_wand/software/cloud/backend/versions/brain_v2_scoring/src/brain/api/server.py)
  - [`parser.py`](/home/bensonyi/FPGA_wand/Information-Processing_Group_10_fpga_wand/software/cloud/backend/versions/brain_v2_scoring/src/brain/ingest/parser.py)
  - [`udp_rx.py`](/home/bensonyi/FPGA_wand/Information-Processing_Group_10_fpga_wand/software/cloud/backend/versions/brain_v2_scoring/src/brain/ingest/udp_rx.py)
- the final integrated backend wrapper, node-control layer, database
  integration, and live web console
  - [`main.py`](/home/bensonyi/FPGA_wand/Information-Processing_Group_10_fpga_wand/software/cloud/main.py)
  - [`node_control.py`](/home/bensonyi/FPGA_wand/Information-Processing_Group_10_fpga_wand/software/cloud/node_control.py)
  - [`models.py`](/home/bensonyi/FPGA_wand/Information-Processing_Group_10_fpga_wand/software/cloud/database/models.py)
  - [`index.html`](/home/bensonyi/FPGA_wand/Information-Processing_Group_10_fpga_wand/software/cloud/frontend/index.html)

The evidence also supports substantial contribution to:

- protocol definition and documentation
- testing and smoke-test tooling
- final architecture, validation, and report-facing documentation

### Technical character of the contribution

The visible develop-branch record is not limited to one subsystem. It spans:

- project setup and management scaffolding
- hardware/software interface definition
- FPGA fallback implementation
- PYNQ runtime implementation
- UDP transmission protocol definition and sender path
- server-side receive/parse/runtime logic
- backend and database integration
- live frontend/dashboard development
- integration testing and final documentation

The conservative interpretation is therefore not merely that Yi contributed
heavily, but that Yi was the primary implemented owner of the final adopted
cross-subsystem delivery path.

### Relation to exploratory work

The branch history also contains earlier exploratory work, including
ESP32/IMU-based wand experimentation from a previous architectural stage.

That exploratory work should be acknowledged, but it should not be confused
with the final adopted architecture. The main report emphasis should remain on
the adopted LED-wand + camera + PYNQ + WandBrain system preserved on
`develop`.

### Final-phase collaboration

The current project record also indicates that the final pre-demonstration
phase involved shared rapid development, testing, and debugging with Wells and
Mingze.

The report should therefore distinguish between:

- Yi’s primary implementation ownership of major parts of the adopted system
- the collaborative nature of the final integration and testing push

### Report-safe interpretation

The safest interpretation for the final report is:

`Using the final adopted develop branch as the main evidence base, Yi was the
primary implemented owner of major parts of the final presented system. This
included the adopted fallback FPGA design path, the PYNQ PS/runtime and UDP
sender path, the final WandBrain ingest/runtime path, and the final integrated
backend, database, and live web interface used in the demonstration. Yi also
contributed substantially to project setup, interface definition, testing, and
documentation. The final pre-demonstration phase nevertheless remained
collaborative, with rapid testing, debugging, and integration work shared with
other committed contributors.`

### Additional management interpretation

If needed for the project-management section, the following wording is
defensible:

`The final adopted system shows a high degree of implementation concentration on
the develop branch, which functioned as the main delivery path for the
presented model. This concentration applied not only to a single subsystem but
to the interfaces between FPGA, node software, UDP communication, backend
runtime, persistence, and user-facing operation.`

### Cautions

- This interpretation relies on the explicit report-preparation assumption that
  `develop` should be treated as Yi’s delivery branch
- where early MVP work by other members exists, it should still be acknowledged
  separately rather than erased by later integration ownership
- final-phase collaborative testing and debugging should be preserved in the
  report so that implementation ownership does not obscure shared recovery
  effort

---

## Wells

### Planned responsibility

Wells was part of the FPGA workstream and was originally associated with the
high-responsibility section covering PL architecture, PS bindings, and general
Zynq/PYNQ-side development.

Because the FPGA path was a critical dependency for end-to-end integration,
this role carried substantial project-management weight.

### Confirmed evidence

The visible GitHub evidence shows two Wells-authored commits on the `Wells`
branch:

- `6533bcc` (`2026-02-22`): adds custom HDL files
  - `conv.v`
  - `imageControl.v`
  - `imageProcessTop.v`
  - `lineBuffer.v`
- `19c422f` (`2026-03-09`): adds or reorganises FPGA hardware artefacts
  including:
  - `design_1.bit`
  - `design_1.hwh`
  - `design_1.tcl`
  - the above HDL files under a hardware folder

This supports the claim that Wells contributed real FPGA development work and
did not remain at planning level only.

### Relation to the final presented model

The branch evidence indicates that Wells pursued a more ambitious FPGA
image-processing design path based around modules such as `imageProcessTop` and
`imageControl`.

This is technically meaningful work, but it is not the same path as the
simpler centroid-based fallback PL design adopted in the final presented model.

The conservative distinction is therefore:

- Wells contributed substantive FPGA architectural and implementation work
- the visible branch artefacts do not appear to be the direct basis of the
  final adopted centroid-based PL implementation

### Final-phase collaboration

According to the current project record, Wells remained committed through the
final phase and participated actively in the last rapid integration, testing,
debugging, and development push alongside Yi and Mingze.

This means the report should distinguish between:

- primary implementation ownership of the adopted FPGA path
- collaborative late-stage validation and recovery effort

### Report-safe interpretation

The safest interpretation for the final report is:

`Wells contributed substantial FPGA architectural work and remained committed
throughout the project. His branch evidence shows a more advanced
image-processing PL design path with custom HDL and hardware export artefacts.
However, this work did not become the main basis of the final adopted
centroid-based FPGA implementation. In the final pre-demonstration phase, Wells
also contributed actively to rapid testing, debugging, and integration work.`

### Additional management interpretation

If needed for the project-management section, the following point is defensible
when phrased carefully:

`The FPGA workstream represented the main critical-path risk. The visible branch
evidence suggests that a comparatively ambitious PL design path was pursued
before a lower-risk working MVP path had been secured, which increased
integration pressure later in the project.`

This should be presented as a project-management observation about technical
strategy and delivery sequencing, not as a personal accusation.

### Cautions

- GitHub evidence supports Wells’s FPGA branch work
- GitHub alone does not prove meeting attendance or all lab-based activity
- claims about final-phase collaboration should be supported by the project
  chronology and direct participant records when used in the report

---

## Ellie

### Planned responsibility

Ellie was part of the backend workstream and was originally associated with the
website, database, and system-level backend path.

This role covered the user-facing frontend as well as the persistence and API
support needed for the cloud side of the system.

### Confirmed evidence

The visible GitHub evidence shows three Ellie-authored commits on the `ellie`
branch:

- `58feeb7` (`2026-02-22`): `demo website`
  - creates `cloud/frontend/index.html`
- `d4ec96d` (`2026-03-02`): `updating database code`
  - adds `cloud/database/database.py`
  - adds `cloud/database/init_db.py`
  - adds `cloud/database/main.py`
  - adds `cloud/database/models.py`
  - updates backend API integration
- `33bfc65` (`2026-03-04`): `updates to api and web page`
  - updates backend API code
  - updates database main logic
  - updates frontend files

This supports the claim that Ellie contributed real backend MVP work across the
frontend, database, and API-facing backend path.

### Technical character of the visible branch work

The visible branch work is consistent with an early backend MVP rather than a
fully developed final production-style backend.

The evidence supports the following specific points:

- a demo website was implemented
- a database layer and `Attempt` model were introduced
- basic API/web integration was added
- the backend API path already aligned with the MVP `/api/v1/*` contract

In particular, the branch includes early implementations of endpoints and data
structures that align with the documented MVP API family, including:

- `/api/v1/health`
- `/api/v1/wands`
- `/api/v1/wand/{wand_id}`
- `/api/v1/attempt/latest`
- `/api/v1/attempt/{attempt_id}/image.png`
- database-backed `Attempt` persistence

### Relation to the final presented model

The safest interpretation is that Ellie’s work established or supported an
early backend MVP path, but that the final backend used in the demonstrated
system was later substantially extended and reworked.

This is important because the final adopted backend includes significantly more
than the MVP branch evidence alone, such as:

- the later WandBrain wrapper structure
- expanded live console behaviour
- node control
- leaderboards
- extended database-backed features
- the final deployed EC2-facing integrated backend

At the same time, the MVP branch should not be dismissed. It provides concrete
evidence of meaningful backend contribution at an earlier stage, particularly
for:

- frontend prototyping
- database scaffolding
- basic backend/API integration

### Report-safe interpretation

The safest interpretation for the final report is:

`Ellie contributed an early backend MVP, including a demo website, database
code, and basic API-facing backend updates. The visible branch evidence shows
meaningful work on frontend structure, persistence, and MVP web APIs. However,
the final deployed backend used for the presented system was later extended and
reworked beyond this MVP stage, so Ellie’s contribution is best described as an
early backend foundation rather than the complete final backend implementation.`

### Additional management interpretation

If needed for the project-management section, the following wording is
defensible:

`The backend workstream did produce visible MVP-stage artefacts, particularly in
the form of website, database, and basic API work. However, the final presented
backend required further extension and integration before it matched the scope
of the adopted system.`

### Cautions

- GitHub evidence clearly supports Ellie’s early backend MVP contribution
- GitHub alone does not prove the full extent of later discussion or support
  activity outside the repository
- the safest distinction is between `early backend MVP work` and `final adopted
  backend ownership`, rather than treating them as identical

---

## Ananya

### Planned responsibility

Ananya was associated with the wand-side track during the earlier planning
phase, when the project still included an ESP32-based wand concept.

This places her planned responsibility within the sensing / wand-side area
rather than the final camera + PYNQ processing path that was eventually
adopted.

### Confirmed evidence

The visible GitHub evidence shows multiple Ananya-authored commits on the
`ananya` branch:

- `a709c7a` (`2026-02-18`): `Create wand_esp32.ino`
- `db8d658` (`2026-02-18`): `uart text protocol`
- `38dae81` (`2026-02-18`): `Add wand pin mapping`
- `b139dfd` (`2026-03-17`): `Create esp32_wand_controller.ino`
- `59f059e` (`2026-03-17`): `Create ir_led_test.ino`
- `2fceea9` (`2026-03-17`): `Create motor_test.ino`
- `0ac3175` (`2026-03-17`): `Create readmeforwand.md`

These commits create concrete artefacts for an ESP32-based wand path,
including:

- ESP32 firmware
- UART text protocol notes
- pin mapping documentation
- IR LED and motor test sketches
- a README describing the ESP32 motion-wand concept

### Technical character of the visible branch work

The branch work is technically coherent and focused on an ESP32/IMU-based wand
concept with:

- MPU6050-based motion sensing
- UART-based output
- IR LED triggering
- haptic motor output
- hardware setup documentation

This means the safest interpretation is **not** that the branch was empty or
purely nominal. It contains real exploratory wand-side implementation work.

### Relation to the final presented model

At the same time, the visible branch work is clearly tied to the ESP32 wand
architecture rather than the final presented LED-wand + camera + PYNQ system.

Based on the current evidence, the conservative distinction is:

- Ananya contributed concrete exploratory ESP32 wand work
- this visible branch work was **not adopted** into the final presented system
- no confirmed adopted contribution to the final LED-wand + camera + PYNQ model
  has been established from GitHub evidence alone

### Report-safe interpretation

The safest interpretation for the final report is:

`Ananya contributed a concrete exploratory ESP32 wand path, including firmware,
protocol notes, and hardware guidance. However, this work was not part of the
final adopted system because the final presented model did not use the
ESP32-based wand architecture.`

### Additional management interpretation

If needed for the project-management section, the following wording is
defensible:

`The wand-side workstream included exploratory implementation effort around an
ESP32-based wand concept. This effort should be acknowledged as real technical
work, but it should be reported separately from the final adopted system
because the project later converged on a different architecture for the
presented model.`

### Cautions

- GitHub evidence supports Ananya’s exploratory ESP32 wand work
- GitHub alone does not prove whether any non-repository support activity also
  occurred outside this branch
- the safest distinction is between `exploratory ESP32 wand contribution` and
  `adopted contribution to the final presented model`

---

## Apshara

### Planned responsibility

Apshara appears in the project record as part of the early wand-side allocation
at the planning stage.

There is also an indication in the current project chronology that Apshara may
later have become associated with backend-side work after role movement during
the project, but this should be treated carefully until the exact contribution
is confirmed.

### Current evidence status

At present, the conservative evidence base for Apshara is limited.

The accessible repository and visible GitHub branches do **not** currently show
a dedicated authored branch or authored commits that can be confidently
attributed to Apshara.

This does **not** justify concluding that no contribution existed. It only
means that the contribution is not currently evidenced strongly enough in the
accessible repository record to describe in specific technical terms.

### Safest current interpretation

The safest interpretation for report preparation is:

- Apshara had a planned role in the project
- current evidence supports discussing that planned role
- actual delivered contribution to the final presented model remains **pending
  confirmation**

### Report-safe interpretation

The safest interpretation for the final report is:

`Apshara was part of the planned team allocation during the project. However,
the exact scope of delivered technical contribution has not yet been confirmed
strongly enough to state in detail, so any final attribution should remain
limited to verified evidence.`

### Cautions

- do not convert lack of visible GitHub evidence into a stronger negative claim
- if later evidence becomes available, this note should be updated
- until then, Apshara should remain in the `pending confirmation` category

---

## Seth

### Planned responsibility

Seth appears in the project planning record as part of the backend-side team.

This places his planned role within the website / database / backend workstream
at the planning stage.

### Current evidence status

At present, the conservative evidence base for Seth is also limited.

The accessible repository and visible GitHub branches do **not** currently show
a dedicated Seth-authored branch or authored commits that can be confidently
used as direct evidence of delivered implementation work.

Again, this should be interpreted as an **evidence gap**, not as a stronger
claim than the evidence supports.

### Safest current interpretation

The safest interpretation for report preparation is:

- Seth had a planned backend role
- current accessible repository evidence does not yet confirm a delivered
  technical contribution to the final presented model
- any stronger attribution should wait until additional evidence is confirmed

### Report-safe interpretation

The safest interpretation for the final report is:

`Seth was part of the planned backend allocation for the project. However, the
current evidence base does not yet confirm a specific delivered technical
contribution strongly enough to describe in detail, so final attribution should
be limited to verified evidence only.`

### Cautions

- do not equate missing GitHub history with proof of no contribution
- if external evidence later confirms work, this note should be revised
- until then, Seth should remain in the `pending confirmation` category

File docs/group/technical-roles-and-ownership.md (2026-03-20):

# Technical Roles and Ownership Structure  
**FPGA-Wand Project**

> This document records the **intended technical ownership structure**
> established during project planning.
>
> It should be read as a statement of the **original allocation of roles and
> responsibilities**, not as a final record of who delivered each adopted part
> of the final presented system.
>
> Final report writing should therefore distinguish between:
>
> - planned responsibility
> - actual delivered work
> - exploratory or partial work that was not adopted in the final model

This document defines the **technical ownership, responsibility boundaries, and integration rules** for the FPGA-Wand project.

The system is a **distributed point-tracking and shape recognition system**, not a gesture-recognition system.  
All design, implementation, and evaluation are based on **explicit spatial tracking and deterministic processing**, rather than learned or semantic gesture inference.

The project is developed across **three concrete engineering tracks**, each owning a clearly scoped subsystem with well-defined inputs and outputs.

This structure is designed to:

- Enable parallel development  
- Prevent responsibility overlap  
- Preserve interface stability  
- Support incremental, testable milestones  

---

## Overview of Technical Tracks

The project is organised into the following tracks:

1. **Optical Wand and Camera Setup** (LED Wand + Camera)  
2. **FPGA Node & Local Processing** (PYNQ-Z1 / Local Runtime)  
3. **Backend, Database & User Interface** (System-level coordination)  

The **FPGA node (PYNQ-Z1)** is the primary processing and decision-making node, as defined by the coursework specification.

The **LED wand + camera setup** together form the optical sensing subsystem
that feeds the FPGA node.

The **Backend, Database, and UI** provide coordination, persistence, and interaction, but are not required for the minimum viable demonstration.

---

## Track 1 — Optical Wand and Camera Setup  
**Owners: Yi, Ananya**

### Scope

This track owns the **physical wand visibility setup and camera-side optical
tracking conditions**.

Its responsibility is to make the physical wand and camera setup produce a
stable bright target that the FPGA node can track reliably.

This track does **not** perform shape recognition or semantic interpretation.

---

### Responsibilities

- Camera setup and calibration  
- Detection of the wand marker (visible LED)  
- Stable physical positioning and optical visibility  
- Lighting and background conditions that support robust tracking  
- Calibration support for the camera/FPGA pipeline  
- Power stability and hardware reliability  

---

### Explicit Non-Responsibilities

- Shape or path classification  
- Path reconstruction or normalisation  
- FPGA hardware design or acceleration  
- Cloud communication  
- User-facing interfaces  

---

### Data Outputs (to FPGA Node)

This track does not define a separate embedded protocol of its own in the final
system. Instead, it provides the physical conditions under which the FPGA node’s
camera pipeline can generate stable 2D tracking results.

---

### Deliverables

- Reliable camera-based optical tracking conditions  
- Wand visibility and alignment notes  
- Calibration and validation notes  

---

### Success Criterion

Moving the LED wand through the tracked space produces:

- stable and visible optical tracking conditions  
- repeatable camera observations of the wand tip  
- usable centroid data on the FPGA node  

---

## Track 2 — FPGA Node & Local Processing  
**Owners: Mingze, Wills**

### Scope

This track owns all **node-side processing, reconstruction, classification, and real-time visual output**.

The **PYNQ-Z1** is the authoritative local processing node and must operate correctly **without backend support**.

---

### Responsibilities

#### Node-Side Software (Processing System)

- Camera frame capture and preprocessing  
- DMA and MMIO orchestration  
- Reading centroid statistics from the PL  
- Filtering and accepting tracked points  
- Local sketch rendering  
- UDP transmission to the backend  
- HTTP node-control polling and acknowledgement  
- Optional local status output for debugging and demo use  

---

#### FPGA Hardware (Programmable Logic)

- Optional acceleration of deterministic processing:
- Filtering or smoothing  
- Feature extraction  
- Distance / error accumulation  
- AXI streaming and DMA interfaces  
- Fixed-point optimisation  
- Performance and resource utilisation measurement  

> A correct software baseline **must exist** before FPGA acceleration.

---

### Explicit Non-Responsibilities

- Sensor acquisition  
- Camera tracking or calibration  
- Backend session management  
- Web-based user interfaces  

---

### Deliverables

- Working local reconstruction and classification pipeline  
- HDMI demo showing live drawing and results  
- FPGA design (if used) with measured benefit  
- Software vs hardware performance comparison  
- Reproducible Jupyter notebooks or scripts  

---

### Success Criterion

The FPGA node can:

- Reconstruct a 2D drawing locally  
- Classify a basic shape (line or circle)  
- Display results in real time via HDMI  

---

## Track 3 — Backend, Database & User Interface  
**Owner: Ellie**  
**Contributors: Seth, Apshara**

### Scope

This track owns all **system-level coordination, persistence, and user-facing interaction**.

It enables multi-node behaviour and extended demonstrations but is **not required for the minimum demo**.

---

### Responsibilities

- Backend server (HTTP + UDP ingest)  
- Multi-node session management  
- Receiving classification results and events from FPGA nodes  
- Sending configuration or mode updates to nodes  
- Database schema and persistence  
- System-level logging and replay  
- User-facing web interface  
- Visualisation of drawings and results  
- System state display  
- Optional competitive or collaborative logic  
- Deployment (local or EC2)  

---

### Explicit Non-Responsibilities

- Sensor handling  
- Vision or tracking logic  
- FPGA or hardware design  
- Real-time HDMI rendering  

---

### Deliverables

- Backend server supporting multiple FPGA nodes  
- Reliable bidirectional communication  
- Database storing system state and results  
- User-facing web interface  
- Deployment and usage documentation  

---

### Success Criterion

Multiple FPGA nodes can:

- Connect to the backend  
- Affect shared system state  
- Be observed and interacted with through a web interface  

---

## Cross-Track Integration Rules

- All interfaces **must be documented** in `software/protocol/`  
- No track may change an interface unilaterally  
- End-to-end demos take priority over internal optimisation  
- Software baselines precede FPGA acceleration  
- Camera-derived 2D position is the **authoritative spatial reference**  

---

## Project Lead & Integration Authority

One member acts as **Project Lead / System Integrator**.

### Responsibilities

- Maintain architectural consistency  
- Approve interface and scope changes  
- Run milestone reviews and accept demos  
- Coordinate merges and feature freezes  

The Project Lead may contribute to a technical track while retaining **final integration authority**.

---

## Definition of Done (All Tracks)

A task is complete only when:

- Functionality works as intended  
- Output can be demonstrated  
- Integration with other tracks is verified  
- Relevant documentation is updated  

This definition applies to **all tracks equally**.

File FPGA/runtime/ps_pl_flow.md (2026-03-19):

# PS / PL Signal And Control Flow

This note explains how the deployed PYNQ runtime and the used PL design work
together. It is based on the actual code in:

- [`pynq_wand_brain_demo.py`](./pynq_wand_brain_demo.py)
- [`pynq_udp_bridge.py`](./pynq_udp_bridge.py)
- [`../designs/centroid_pipeline/used_version/source/frame_centroid.v`](../designs/centroid_pipeline/used_version/source/frame_centroid.v)

## Design Intent

The project does not use the PL to perform the entire vision pipeline. The PS
and PL are split deliberately:

- the PS handles camera capture, image preprocessing, system control, local
  sketching, and networking
- the PL performs the regular per-pixel reduction step that is expensive to do
  repeatedly in software

The reduction result is a compact statistical summary of the frame rather than
another image stream.

## Startup Sequence

At startup, the PS performs these steps:

1. Load the bitstream with `Overlay(BIT)`.
2. Inspect `ol.ip_dict` and locate the DMA and centroid IP instances.
3. Open an AXI-Lite MMIO window for the centroid IP.
4. Allocate a flat DMA buffer of size `H * W`.
5. Open and warm up the camera.
6. Create the `WandBrainUdpBridge` for UDP data transmission and HTTP control.
7. Call the backend health endpoint.
8. Fetch the initial node-control payload and apply it before entering the main
   loop.

This means the PS establishes both the PL path and the cloud path before it
starts drawing.

## Signal Flow: Camera To PL

For every loop iteration, the PS starts with a camera frame:

1. `cap.read()` returns a BGR frame from the USB camera.
2. `preprocess_frame(...)` converts it to grayscale.
3. The frame is resized to `640 x 480`.
4. A Gaussian blur is applied to suppress small pixel noise.
5. A binary threshold is applied, producing an 8-bit foreground mask where
   bright pixels become `255` and dark pixels become `0`.

The preprocessed frame is then sent into the PL:

1. The binary image is flattened into the DMA buffer.
2. `dma.sendchannel.transfer(buf)` starts the AXI DMA transfer.
3. `dma.sendchannel.wait()` blocks until the full frame has been streamed.

Architecturally, this is a one-way memory-to-stream path:

- the PS writes the frame into DDR-backed memory
- the DMA reads from memory
- the custom IP consumes an AXI4-Stream

There is no stream coming back from the PL. The result returns through
registers.

## Signal Flow Inside The PL

The custom module `frame_centroid` consumes the DMA stream through:

- `s_axis_tdata[31:0]`
- `s_axis_tvalid`
- `s_axis_tready`
- `s_axis_tlast`

The important implementation details are:

1. `s_axis_tready` is hard-wired to `1`, so the IP is always willing to accept
   data.
2. Each 32-bit AXI beat carries four 8-bit grayscale pixels.
3. The module unpacks those four pixels as `p0..p3`.
4. It associates them with four x-coordinates `x0..x3`.
5. Each pixel is tested against `THRESHOLD`.
6. For bright pixels only, the module increments:
   - `bright_count`
   - `sum_x`
   - `sum_y`
7. The internal `x` counter advances by four pixels per beat.
8. When the end of a row is reached, `x` wraps to zero and `y` increments.
9. A frame ends when either:
   - `s_axis_tlast` is asserted, or
   - the expected `WIDTH * HEIGHT` pixels have been consumed
10. At frame end, the module latches:
   - `o_sum_x`
   - `o_sum_y`
   - `o_count`
   - `o_frame_id`
   - `o_valid`
11. The running accumulators are then reset for the next frame.

In the deployed pipeline, the PS already sends a binary image. That means the
PL threshold test is effectively selecting the `255` foreground pixels.

## Signal Flow: PL Back To The PS

After the DMA transfer completes, the PS reads the centroid IP registers using
MMIO:

- `0x00` / `0x04`: `sum_x`
- `0x08` / `0x0C`: `sum_y`
- `0x10`: `count`
- `0x14`: `frame_id`
- `0x18`: `valid`

The PS reconstructs the 40-bit sums and computes:

- `cx = sum_x // count`
- `cy = sum_y // count`

This is an intentional boundary:

- the PL provides raw statistics
- the PS performs the division and all later policy decisions

## Freshness And Duplicate Handling

One subtle but important detail is that the HDL sets `o_valid <= 1'b1` when a
frame completes, but it does not clear `o_valid` again until reset. In other
words, `valid` behaves like a sticky "results available" flag, not a one-cycle
fresh-data pulse.

Because of that, the PS does not rely on `valid` alone. It also tracks
`frame_id`:

- `new_result = (frame_id != last_frame_id)`

This lets the runtime distinguish:

- a genuinely new hardware result
- a repeated read of the same latched result

That detail matters again in the UDP sender. The bridge stores the
`last_sent_frame_id`, and if the PS sees the same hardware result again, it
returns `hold_duplicate` instead of sending another point packet. This prevents
duplicate network points while still keeping the current stroke alive.

## Runtime Control Flow On The PS

The PS loop is not just a passive reader of PL output. It is the main control
plane of the node.

The runtime maintains:

- `runtime_state`
  current applied control values such as threshold, min-count, gap timeout, and
  mode
- `drawing_state`
  local sketch canvas and previous point history
- `pending_control`
  a control revision that was received but intentionally delayed

Every `CONTROL_POLL_INTERVAL_MS`, the PS:

1. polls `/api/v3/node/{device}/control`
2. merges the payload into effective settings
3. either applies the new revision immediately, or queues it until the active
   stroke has ended

This `apply_on` behavior is important:

- `immediate` means the control change is safe to apply now
- `next_attempt` means the runtime waits until the node is idle so an active
  stroke is not corrupted halfway through

The PS also posts periodic acknowledgements back to the server, including:

- applied revision
- whether a stroke is active
- whether transmission is active
- pending revision
- last error, if any

## Per-Frame Decision Flow

Once the current centroid statistics are available, the PS makes a series of
gating decisions.

### 1. Hardware-level validity

The PS forms:

- `valid_hw = bool(stats["valid"]) and stats["count"] >= min_count`

So the PL says "a frame result exists", and the PS adds the stronger policy
that the blob must contain enough bright pixels.

### 2. Node-level enable state

The PS forms:

- `tracking_enabled = enabled and armed`

This is how the server can control the board without changing the bitstream:

- `enabled = false` blocks tracking completely
- `armed = false` keeps the node alive but prevents normal stroke operation
- `tx_enabled = false` allows local logic to keep running but blocks upstream
  UDP transmission

### 3. UDP emission decision

The PS forms:

- `valid_for_udp = tracking_enabled and tx_enabled and valid_hw`

If this is true, the centroid is handed to `bridge.process_point(...)`.

The bridge then performs the network-side stroke state machine:

- start a new stroke on the first valid point after idle
- send one UDP packet for each valid point
- normalize pixel coordinates to `[0, 1]`
- convert them to Q15 integers
- set `PEN_DOWN`, `STROKE_START`, or `STROKE_END`
- end the stroke after `gap_timeout_ms` without a valid point

This means the PS decides whether a point is acceptable, while the bridge
decides how that accepted point should be packetized as part of a stroke.

### 4. Local sketch decision

Separately, the PS forms:

- `valid_for_sketch = tracking_enabled and new_result and valid_hw`

So the local notebook sketch is intentionally tied to fresh hardware results.
That avoids drawing the same latched centroid repeatedly.

When a sketch point is accepted, the PS:

1. mirrors the x-coordinate for presentation
2. maps the centroid from camera coordinates into sketch coordinates
3. smooths the point using `smoothing_alpha`
4. rejects implausibly large jumps using `max_jump`
5. draws either:
   - a line from the previous accepted point, or
   - an isolated point if no line is appropriate

## Server-Controlled Behavior

The interesting control features live almost entirely in the PS rather than the
PL. The server can influence:

- `threshold`
- `min_count`
- `gap_timeout_ms`
- `max_jump`
- `smoothing_alpha`
- `enabled`
- `armed`
- `tx_enabled`
- mode selection such as `normal`, `precision`, `fast`, and `noisy_room`

One-shot command tokens can also trigger:

- sketch clearing
- threshold recalibration using fresh camera frames

This is a key architectural choice of the final system:

- the PL stays stable and focused on frame reduction
- the PS remains flexible and can change behavior live through HTTP control

## Why This Split Worked Well

This PS/PL boundary was a good fit for the project because:

- the most repetitive per-pixel operation moved into hardware
- the PS still had full freedom to tune thresholds and stroke logic
- integration with the camera and the EC2 backend stayed simple
- debugging was manageable because the PL output was small and interpretable
- the cloud control path could change runtime behavior without requiring a new
  FPGA bitstream

In short, the PL acts as a centroid-statistics accelerator, while the PS acts
as the node controller.

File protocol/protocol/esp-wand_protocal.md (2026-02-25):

# ESP32 Wand Control (MVP v1) — User Story + Control Logic
**Scope:** ESP32 handles **button → IR LED + haptic** and sends **START/END events** to PYNQ.  
**IMU:** Ignored for MVP (single-go configuration, no runtime use).  
**Segmentation model:** One **attempt** per button-hold (press → release). PYNQ collects `(x,y,t)` only during an active attempt.

---

## 1) User Story (what the user experiences)

1. User holds the wand and **presses & holds** the button to begin.
2. Immediately on press:
   - IR LED turns **ON** (tracking enabled).
   - Wand signals PYNQ: **START** (new attempt begins).
3. After **3 seconds** of continuous holding:
   - Motor **vibrates once** to indicate “ready / start drawing now”.
4. User draws while continuing to hold the button.
5. When finished, user **releases** the button:
   - Motor **vibrates once** to confirm end.
   - IR LED turns **OFF**.
   - Wand signals PYNQ: **END** (attempt ends; PYNQ/brain can finalize scoring).

Notes:
- If the user releases before 3 seconds, the “ready” vibration does not happen, but END still happens normally.

---

## 2) Interface: ESP32 → PYNQ Event Signaling

ESP32 sends **events only** (not continuous streams).

### Required events
- `START`: button press accepted (debounced)
- `END`: button release accepted (debounced)

### Optional event (recommended for UX, not required by backend)
- `READY`: emitted at press + 3s (when the motor vibrates)

### Transport
- UART or UDP (team choice). Content below is transport-agnostic.

### Message content (minimum fields)
- `proto`: fixed version tag
- `seq`: monotonic uint32 sequence number
- `event`: `START` / `READY` / `END`
- `attempt_id`: monotonic uint32 (increments per press)
- `ts_ms`: ESP32 local ms since boot (for logging/debug only)

**Example (ASCII line format, easiest to debug):**
- `EVT,proto=wand-evt@1,seq=10,event=START,attempt=57,ts=123456\n`
- `EVT,proto=wand-evt@1,seq=11,event=READY,attempt=57,ts=126456\n`
- `EVT,proto=wand-evt@1,seq=12,event=END,attempt=57,ts=130012\n`

PYNQ behavior:
- On `START(attempt_id)`: begin accepting blob points into this attempt.
- On `END(attempt_id)`: stop accepting; flush/close attempt; backend can score.

---

## 3) Control Logic (Authoritative State Machine)

### Outputs
- `LED_IR`: ON/OFF
- `MOTOR`: vibrate pulse

### Inputs
- `BTN`: button pressed/released (debounced)

### Timing constants (defaults)
- `T_READY_MS = 3000` (press-and-hold time before READY vibration)
- `VIB_READY_MS = 120` (vibration pulse duration at READY)
- `VIB_END_MS = 120` (vibration pulse duration at END)
- `DEBOUNCE_MS = 30` (button debounce time)

### States
- `IDLE`: button not pressed, LED off
- `HOLDING`: button pressed, LED on, waiting for READY
- `ACTIVE`: READY already issued, still holding

### Transitions

#### IDLE → HOLDING (debounced press)
Actions (immediate):
- `attempt_id += 1`
- `seq += 1; send_event(START, attempt_id)`
- `LED_IR = ON`
- record `t_press_ms = now_ms()`
- set `ready_sent = false`

#### HOLDING → ACTIVE (if still pressed and now_ms() - t_press_ms ≥ T_READY_MS)
Actions:
- `pulse_motor(VIB_READY_MS)`
- (optional) `seq += 1; send_event(READY, attempt_id)`
- set `ready_sent = true`

#### HOLDING → IDLE (debounced release before READY time)
Actions:
- `pulse_motor(VIB_END_MS)`
- `LED_IR = OFF`
- `seq += 1; send_event(END, attempt_id)`
- reset internal counters

#### ACTIVE → IDLE (debounced release)
Actions:
- `pulse_motor(VIB_END_MS)`
- `LED_IR = OFF`
- `seq += 1; send_event(END, attempt_id)`
- reset internal counters

---

## 4) Requirements / Guarantees

### Guarantees ESP32 provides to PYNQ
- Exactly **one START** per attempt.
- Exactly **one END** per attempt.
- `attempt_id` is strictly increasing.
- `seq` is strictly increasing (detect drops/duplicates).
- LED is ON for the entire time between START and END (minus hardware propagation delays).

### Debounce requirement
- ESP32 must debounce button to avoid multiple START/END events from contact bounce.

### Failure handling (MVP)
- If communication fails, LED/motor behavior remains correct; PYNQ may miss events (acceptable for MVP, but log it).

---

## 5) Integration Notes (for the PYNQ team)
- Treat `attempt_id` as the grouping key for all `(x,y,t)` samples during the button-hold.
- Ignore ESP32 timestamps for fusion; use PYNQ local time for camera frames.
- If READY is implemented: it is a UX marker, not required for scoring.

---

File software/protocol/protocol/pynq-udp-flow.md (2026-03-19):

# PYNQ UDP Transmission, Receive, And Parse Flow

This note explains the full `wb-point-v1` path from the PYNQ board to Wand
Brain. It complements the packet contract in
[`pynq-udp-brian-v1.md`](./pynq-udp-brian-v1.md) by showing how the protocol is
actually used in the deployed system.

The main implementation files are:

- PYNQ sender and runtime gating:
  [`../../../FPGA/runtime/pynq_wand_brain_demo.py`](../../../FPGA/runtime/pynq_wand_brain_demo.py)
- PYNQ UDP bridge:
  [`../../../FPGA/runtime/pynq_udp_bridge.py`](../../../FPGA/runtime/pynq_udp_bridge.py)
- cloud UDP receiver:
  [`../../cloud/backend/versions/brain_v2_scoring/src/brain/ingest/udp_rx.py`](../../cloud/backend/versions/brain_v2_scoring/src/brain/ingest/udp_rx.py)
- cloud packet parser:
  [`../../cloud/backend/versions/brain_v2_scoring/src/brain/ingest/parser.py`](../../cloud/backend/versions/brain_v2_scoring/src/brain/ingest/parser.py)
- cloud state machine:
  [`../../cloud/backend/versions/brain_v2_scoring/src/brain/api/server.py`](../../cloud/backend/versions/brain_v2_scoring/src/brain/api/server.py)

## Contract Summary

The protocol spec already defines the wire-level contract:

> **Direction:** PYNQ -> Wand Brain  
> **Protocol name:** `wb-point-v1`  
> **Transport:** UDP  
> **Packet size:** 24 bytes fixed  
> **Endianness:** little-endian

The spec also defines the sender-side stroke semantics:

> first valid point after idle => `STROKE_START | PEN_DOWN`  
> middle valid points => `PEN_DOWN`  
> one final packet after the stroke ends => `STROKE_END`

Those two short quotes are the whole idea of the data plane:

- one UDP datagram carries one point sample
- the packet flags describe where that point sits in the stroke lifecycle

## Why UDP Is Used Here

The project uses UDP as a low-latency point-stream transport rather than a
reliable byte stream.

That matches the system architecture well:

- the board sends frequent, small, independent point updates
- the backend can tolerate occasional packet loss better than retransmission
  delay
- the stroke lifecycle is expressed explicitly with packet flags
- the control plane is handled separately over HTTP, so the UDP path can stay
  narrow and fast

In this design:

- UDP is the drawing data plane
- HTTP is the control and monitoring plane

## Stage 1: PS Decides Whether A Centroid Becomes A Network Point

The PS runtime does not transmit every camera frame. It first decides whether
the current hardware result is good enough to be used.

In [`pynq_wand_brain_demo.py`](../../../FPGA/runtime/pynq_wand_brain_demo.py),
the runtime:

1. captures a camera frame
2. preprocesses it into a binary image
3. streams that frame into the PL through AXI DMA
4. reads back the centroid statistics through MMIO
5. computes the centroid in software
6. decides whether the result is valid for sketching and/or UDP

The key gating values are:

- `valid_hw`
  true only if the hardware result is marked valid and the bright-pixel count
  is at least `min_count`
- `tracking_enabled`
  true only if the node is both `enabled` and `armed`
- `valid_for_udp`
  true only if tracking is enabled, transmission is enabled, and the hardware
  result passed the software acceptance test

So the PS performs policy before networking. The PL provides centroid
statistics, but the PS decides whether those statistics should become a point on
the wire.

## Stage 2: PYNQ Sender Builds A Stroke

The stateful network sender is
[`pynq_udp_bridge.py`](../../../FPGA/runtime/pynq_udp_bridge.py).

Its job is not just "send one packet". It also manages stroke lifecycle.

### Bridge Configuration

The bridge is configured with:

- `brain_host`
- `brain_udp_port`
- `brain_api_port`
- `device_number`
- `wand_id`
- `starting_stroke_id`
- `starting_packet_number`
- `gap_timeout_ms`
- optional `mirror_x` and `mirror_y`

These fields split into two groups:

- transport and identity:
  `brain_host`, `brain_udp_port`, `device_number`, `wand_id`
- stroke behavior:
  `starting_stroke_id`, `starting_packet_number`, `gap_timeout_ms`

### Coordinate Normalization

The PS passes centroid coordinates into the bridge in pixel units:

- `x_px`
- `y_px`
- `src_w`
- `src_h`

The bridge converts those into normalized coordinates:

- `x = x_px / (src_w - 1)`
- `y = y_px / (src_h - 1)`

Optional mirroring is applied here, not in the protocol parser:

- `mirror_x` flips the normalized x coordinate
- `mirror_y` flips the normalized y coordinate

After that, the bridge converts the normalized coordinates into Q15 integers:

- `x_q = round(x * 32767)`
- `y_q = round(y * 32767)`

That matches the protocol spec exactly and makes the packet independent of the
camera resolution.

### Stroke State Machine On The Board

The sender keeps internal state:

- `packet_number`
- `next_stroke_id`
- `active_stroke_id`
- `last_valid_ms`
- `last_valid_q15`
- `last_sent_frame_id`
- `sent_points_in_stroke`

This allows it to interpret a stream of accepted centroid points as a stroke.

The runtime calls:

```python
bridge.process_point(
    valid=valid_for_udp,
    x_px=stats["cx"] if valid_for_udp else None,
    y_px=stats["cy"] if valid_for_udp else None,
    src_w=W,
    src_h=H,
    timestamp_ms=None,
    frame_id=frame_id,
)
```

From there, the sender behavior is:

1. If the current point is valid and there is no active stroke:
   - allocate a new `stroke_id`
   - send a packet with `STROKE_START | PEN_DOWN`
2. If the point is valid and a stroke is already active:
   - send a packet with `PEN_DOWN`
3. If there has been no valid point for at least `gap_timeout_ms`:
   - send one final packet with `STROKE_END`
   - close the sender-side stroke

This is how "wand visible now" gets turned into a structured stroke over UDP.

### Duplicate Hardware Result Suppression

There is one subtle but important sender behavior.

The PL `valid` flag is effectively sticky after a completed frame, so the PS
may re-read the same hardware result multiple times. To avoid sending duplicate
network points, the sender tracks `last_sent_frame_id`.

If:

- the point is valid
- a stroke is already active
- the same `frame_id` is seen again

then the bridge returns `hold_duplicate` and does not emit a new packet.

However, it still updates `last_valid_ms`, which keeps the stroke alive.

This is a good example of where the board-side sender logic and the hardware
interface are tightly coupled.

## Stage 3: Packet Layout On The Wire

The binary packet format is defined in
[`pynq-udp-brian-v1.md`](./pynq-udp-brian-v1.md).

The sender and parser both use the same struct layout:

```text
<HBBHHIIhhI
```

That expands to:

1. `uint16 magic`
2. `uint8 version`
3. `uint8 flags`
4. `uint16 device_number`
5. `uint16 wand_id`
6. `uint32 packet_number`
7. `uint32 stroke_id`
8. `int16 x_q`
9. `int16 y_q`
10. `uint32 timestamp_ms`

The bridge packs that structure using:

```python
WB_STRUCT.pack(
    WB_MAGIC,
    WB_VERSION,
    flags,
    self.cfg.device_number,
    self.cfg.wand_id,
    self.packet_number,
    stroke_id,
    x_q,
    y_q,
    timestamp_ms & 0xFFFFFFFF,
)
```

The important field meanings in the deployed system are:

- `device_number`
  identifies the physical PYNQ board
- `wand_id`
  identifies the wand / player
- `packet_number`
  is monotonic per sender instance
- `stroke_id`
  identifies the source-side stroke
- `timestamp_ms`
  is the sender timestamp truncated to 32 bits

The backend intentionally does **not** treat `stroke_id` as a guaranteed global
attempt identifier. It is treated as source metadata.

## Stage 4: Raw UDP Reception On The Server

The cloud-side receive loop lives in
[`udp_rx.py`](../../cloud/backend/versions/brain_v2_scoring/src/brain/ingest/udp_rx.py).

The `UdpReceiver`:

- creates a UDP socket
- binds to `0.0.0.0:41000`
- sets a receive timeout
- loops in a background thread
- calls `recvfrom(...)`
- stores the latest raw packet and source address
- forwards the raw packet to a callback

This module is deliberately thin. It does not parse or interpret the packet. It
is just the socket ingress layer.

## Stage 5: Packet Parsing

The packet parser lives in
[`parser.py`](../../cloud/backend/versions/brain_v2_scoring/src/brain/ingest/parser.py).

Its job is:

- validate the binary packet
- unpack the fields
- convert them into a typed `PointEvent`

### Validation Rules

For the `wb-point-v1` path, the parser rejects a packet if:

- length is not exactly `24`
- `magic` is not `0x5742`
- `version` is not `1`
- `x_q` or `y_q` is outside `0..32767`

If all checks pass, the parser constructs a `PointEvent` containing:

- `device_number`
- `wand_id`
- `stroke_id`
- `packet_number`
- `x`
- `y`
- `timestamp_ms`
- `flags`
- `pen_down`
- `stroke_start`
- `stroke_end`

The numeric coordinates are converted back to normalized floats:

- `x = x_q / 32767.0`
- `y = y_q / 32767.0`

So the parser is the boundary between:

- raw bytes on the socket
- semantic events for the backend state machine

### Legacy CSV Fallback

The parser still contains an optional legacy CSV fallback for development:

- `x,y,t,wand`

That is not the primary deployed path for the current system. The final PYNQ
integration uses the fixed-size binary format.

## Stage 6: Parsed Event To Live Attempt

Once a packet is parsed successfully, the receive callback in
[`server.py`](../../cloud/backend/versions/brain_v2_scoring/src/brain/api/server.py)
calls:

```python
ev = parse_packet(raw)
if ev is None:
    return
state.on_event(ev)
```

This is where the parser stops and the application logic starts.

The `BrainState` object then:

1. finalizes stale idle attempts if needed
2. records the latest event
3. ensures a `WandStatus` exists for the given `wand_id`
4. decides whether the packet is point-like
5. resolves which internal attempt the event belongs to
6. appends the point into the live attempt buffer
7. finalizes the attempt if `stroke_end` is set

### Why The Backend Has Internal Attempt IDs

The source packet contains `stroke_id`, but the server does not rely on that as
the permanent database identity.

Instead:

- `stroke_id` is preserved as `source_stroke_id`
- the backend generates its own internal `attempt_id`

This avoids collisions when:

- a sender restarts
- `stroke_id` values are reused
- multiple sessions occur over time

This distinction is one of the most important things to understand in the
current Wand Brain backend.

### Attempt Resolution

The backend keeps a `WandStatus` per wand. When a new point arrives, it uses
the current `wand_id`, `device_number`, active attempt state, and
`source_stroke_id` to decide whether the point belongs to:

- the currently active internal attempt, or
- a newly allocated internal attempt

If an active attempt is replaced unexpectedly, the server finalizes the old one
with `close_reason="attempt_replaced"`.

## Stage 7: Stroke Finalization

The server can finalize a stroke in two ways.

### Explicit Finalization

If the packet has `stroke_end = True`, the backend finalizes the current
attempt immediately with:

- `close_reason = "explicit_end"`

This corresponds to the board sending the final `STROKE_END` packet.

### Idle Finalization

The server also runs an idle finalizer thread. If packets stop arriving for an
active attempt and the idle timeout expires, the attempt is finalized with:

- `close_reason = "idle_timeout"`

This is a safety mechanism in case:

- the sender stops unexpectedly
- the end packet is not seen
- the stroke just naturally fades out without another point

### Tiny Fragment Discard

If an idle-finalized attempt contains fewer than the configured minimum number
of points, the backend discards it instead of keeping it as a real result.

That behavior is important because it suppresses tiny accidental fragments caused
by noise or one-frame false starts.

## Stage 8: Live Render And Final Output

Although this note focuses on transmission and parsing, the last step is useful
to understand because it shows why the UDP path exists in the first place.

As points are appended to an attempt buffer, the backend periodically rasterizes
them into a live PNG for the website. When the attempt is finalized, the server:

- renders a final PNG
- stores final metadata
- exposes that attempt through HTTP endpoints

So the full chain is:

1. centroid accepted on the board
2. UDP packet emitted
3. raw datagram received on port `41000`
4. binary packet parsed into a `PointEvent`
5. point appended to the live attempt buffer
6. live and final drawings rendered from the point list

## End-To-End Summary

The cleanest way to describe the current UDP path is:

1. The PS decides whether the current centroid is good enough to transmit.
2. The PYNQ bridge normalizes the centroid, manages stroke state, and packs one
   `wb-point-v1` packet per point.
3. The server-side UDP receiver accepts raw datagrams on port `41000`.
4. The parser validates the 24-byte packet and converts it into a `PointEvent`.
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

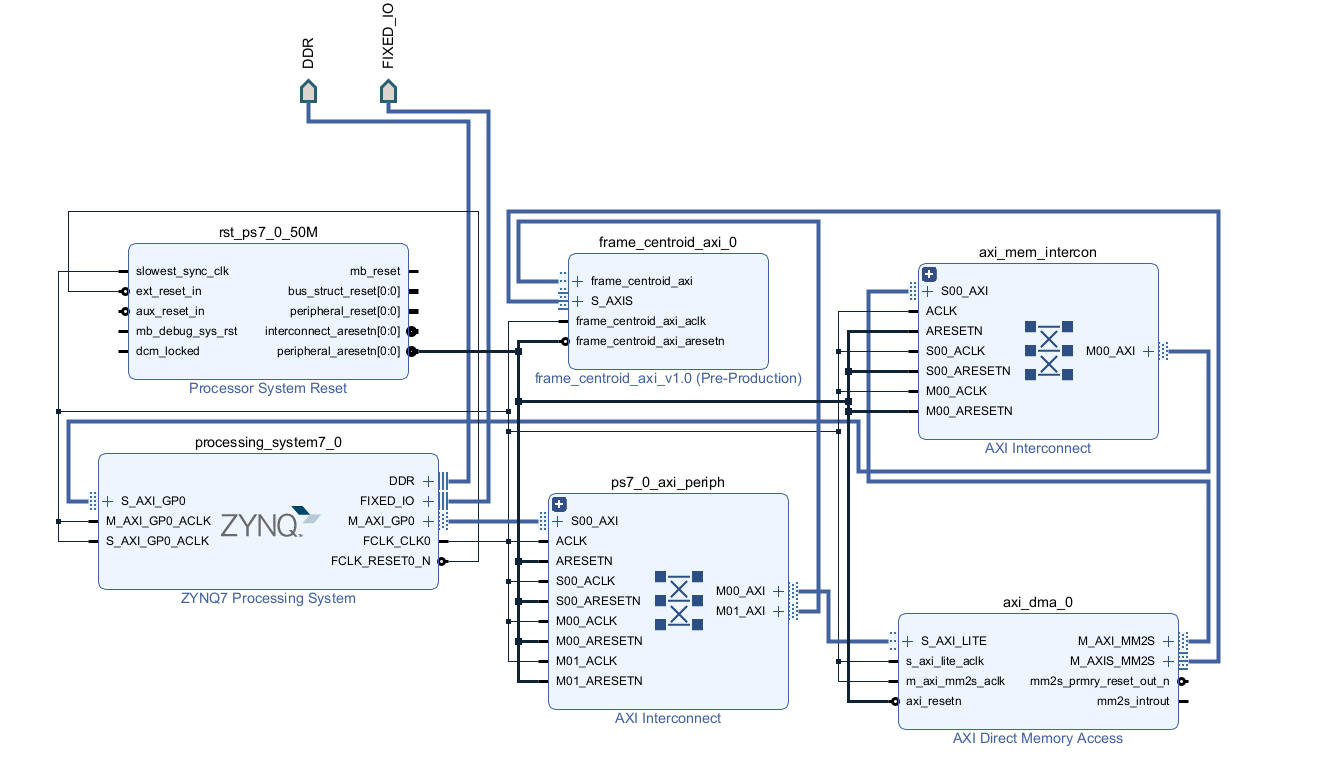
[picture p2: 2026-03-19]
FPGA/designs/centroid_pipeline/used_version/images/top.png

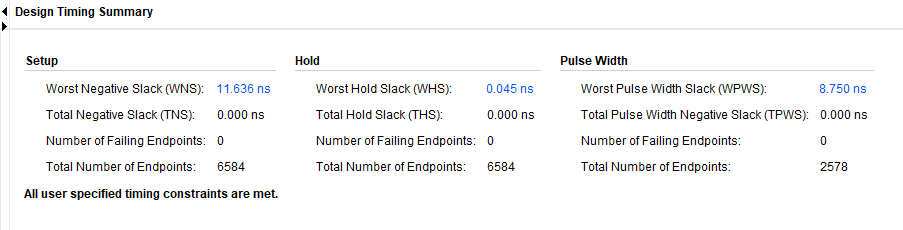
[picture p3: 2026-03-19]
FPGA/designs/centroid_pipeline/used_version/images/timing.png

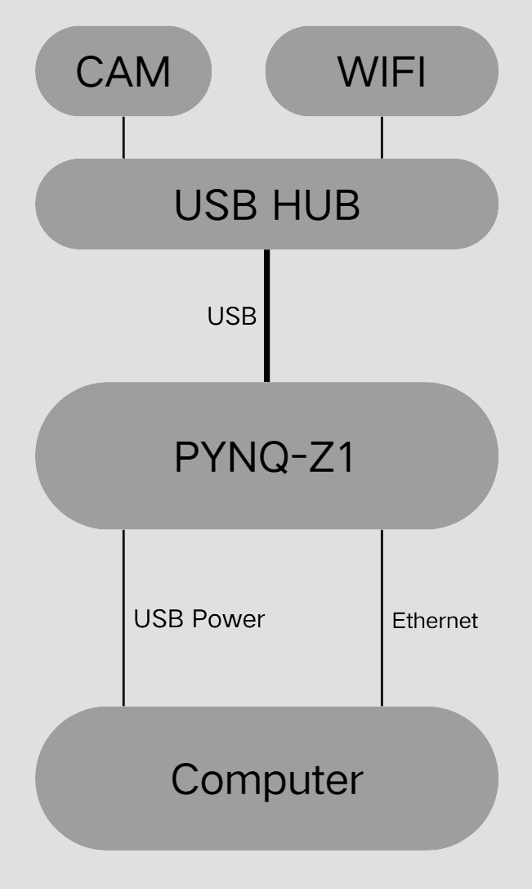
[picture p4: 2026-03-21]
hardware/Single_Node_Layout.png

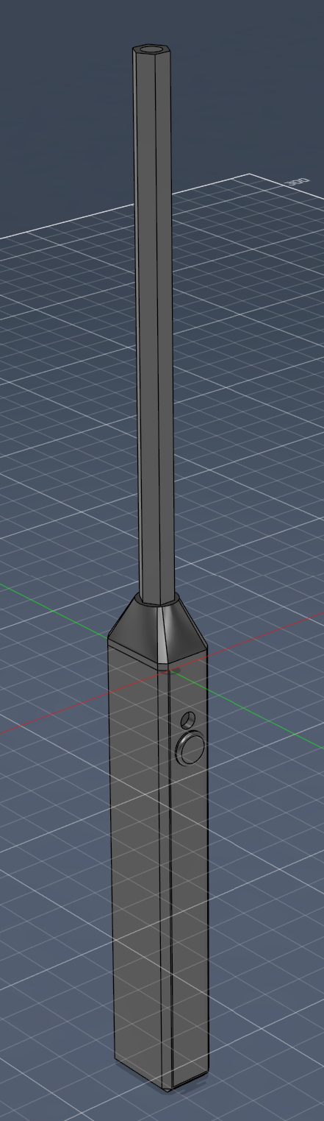
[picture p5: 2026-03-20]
hardware/wand/current_led_wand/Wand.png

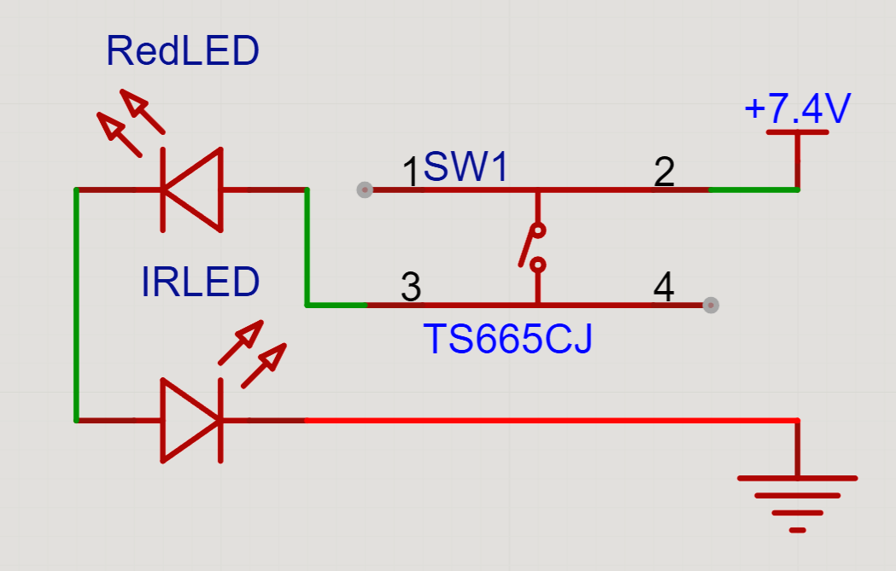
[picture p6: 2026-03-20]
hardware/wand/current_led_wand/Wand_schematic.png

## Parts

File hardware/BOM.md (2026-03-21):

# Bill of Materials (BOM)

| Item | Part Number | Description | Qty | Manufacturer | Supplier / MPN | Reference Designator | Notes |
|---|---|---|-----|---|---|---|---|
| 1 | B0332 | Arducam OV9281 Global Shutter UVC Camera | 2 | Arducam | Arducam B0332 | CAM1, CAM2 | Monochrome, global shutter, 1 MP, UVC. Includes 1m cable with B4B‑ZR connector. |
| 2 | MT-12-2.8-70 | M12 lens 2.8mm EFL, 70° FOV | 2 | Generic / Arducam | AR0135 / 2816 | LENS1, LENS2 | IR sensitive, no IR cut filter. *Optional: camera module already ships with a lens; this line can be removed if not needed.* |
| 3 | USB‑2‑B4B‑1M | USB 2.0 Type‑A to B4B‑ZR cable, 1m | 2 | Generic | Custom cable | J1, J2 | Connects camera to host (PYNQ‑Z1). B4B‑ZR mates with camera connector. |
| 4 | BRKT‑CAM | 3D printed mounting bracket | 2 | Custom | STL file | BRKT1, BRKT2 | PLA or PETG. Designed for 34×34 mm or 28×28 mm hole pattern. Includes alignment features for wand case. |
| 5 | IR‑FILT‑850 | 850nm IR bandpass filter | 2 | Generic | Edmund Optics / etc.  | FILT1, FILT2 | Optional: screws onto M12 lens to block visible light while passing 850nm IR. |
| 6 | IR‑LED‑940 | 940nm IR LED, 5mm or SMD | 2 | Generic | Vishay / etc. | D1, D2 | For IR illumination. Peak wavelength 940nm, typical forward current 50‑100mA. Requires current‑limiting resistor. |
| 7 | LED‑RED | Red LED, 3mm or 5mm | 2 | Generic | Any | LED1, LED2 | Status indicator. 2V forward voltage, 20mA typical. |
| 8 | SW‑PUSH | Momentary push button | 2 | Generic | Any | SW1, SW2 | Tactile switch, through‑hole or SMD. Used for user input (e.g., capture trigger). |
| 9 | PYNQ‑Z1 | PYNQ‑Z1 FPGA development board | 2 | Digilent | Digilent 410‑346 | U1, U2 | Zynq‑7020 SoC. Provides USB host ports, GPIO, and power input (5V/12V). |
| 10 | USB‑HUB‑4 | USB 2.0 4‑port hub | 2 | Ugreen / Anker | Ugreen 20847 | HUB1, HUB2 | Expands USB ports on PYNQ‑Z1. Connect both cameras and WiFi adapter. |
| 11 | WIFI‑USB | USB WiFi adapter | 2 | Generic | TP‑Link TL‑WN823N | WIFI1, WIFI2 | 802.11n/ac, supports Linux (for PYNQ OS). Enables wireless control and data streaming. |
| 12 | BAT‑7.4‑2S | 7.4V Li‑ion battery pack (2S) | 2 | Generic | Any 2S Li‑Po | BT1, BT2 | Capacity ≥ 2000mAh recommended. Must be paired with a 2S Li‑Po charger and protection board. |
| 13 | CASE‑WAND | 3D printed wand case | 2 | Custom | STL file | ENC1, ENC2 | Encases all electronics. Includes mounting points for cameras, battery, and PYNQ‑Z1. Designed for handheld use. |

**Additional Notes:**
- **Power regulation**: The PYNQ‑Z1 accepts 5V (via USB) or 12V (via barrel jack). If using a 7.4V battery, a 12V boost regulator (or a 5V buck regulator for USB power) may be required. Consider adding a DC‑DC converter (e.g., item 14) to supply stable voltage.
- **Cables**: The B4B‑ZR to USB cable is custom; verify pinout matches the camera module’s datasheet. Alternatively, use the cable included with the camera (item 1) and omit item 3 if it already provides a standard USB connector.
- **Assembly**: 3D printed parts (items 4, 13) should be printed with appropriate infill and material for durability. STL files are to be designed based on the mechanical layout.

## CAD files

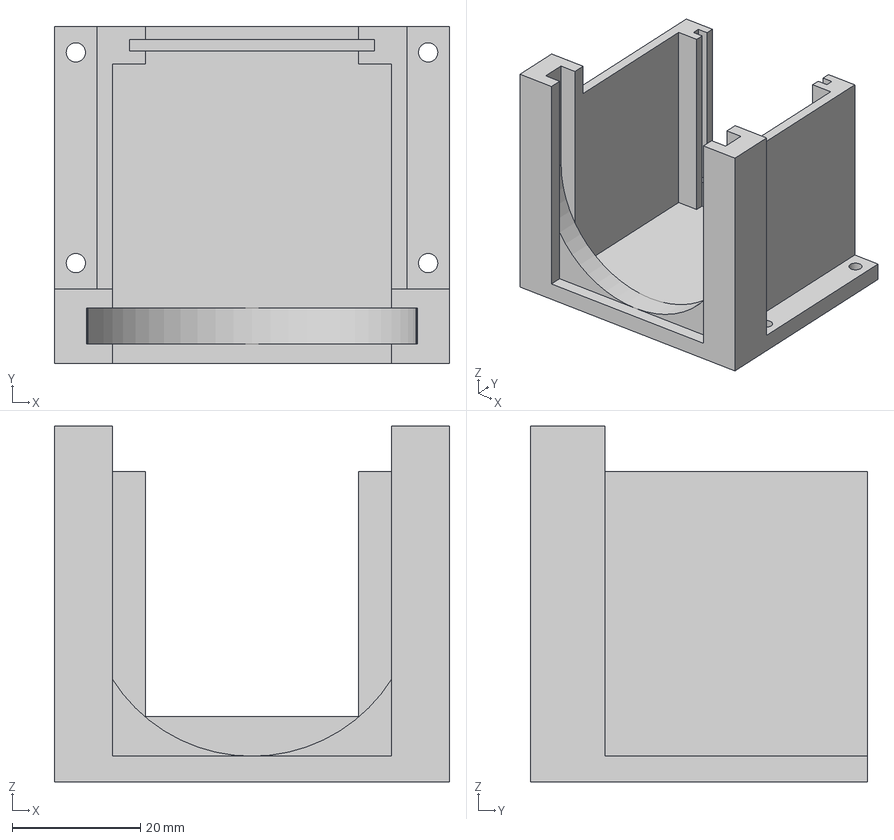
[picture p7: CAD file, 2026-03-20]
hardware/camera/CamMount/CamTestStand v2.step
61.5 x 52.4 x 55.4 mm

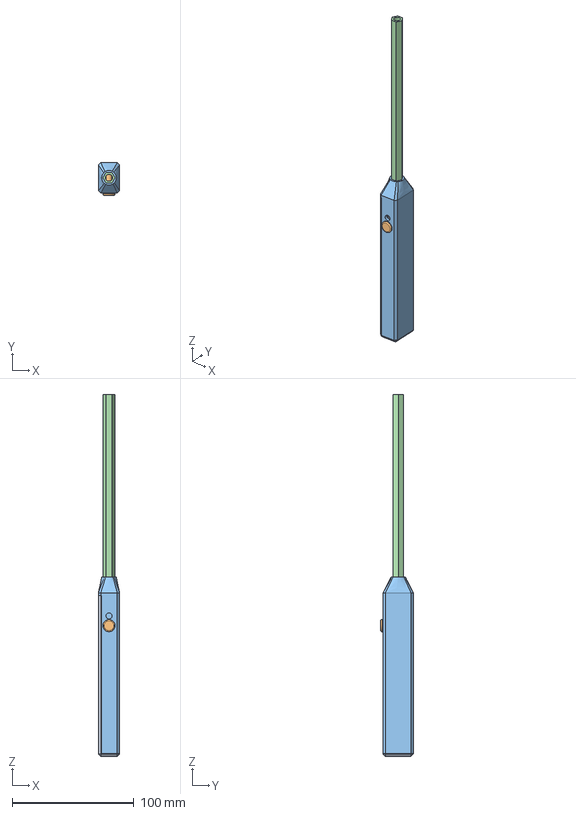
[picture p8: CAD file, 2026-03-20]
hardware/wand/current_led_wand/wand v4.step
17.5 x 27.0 x 297.5 mm
零部件1
button

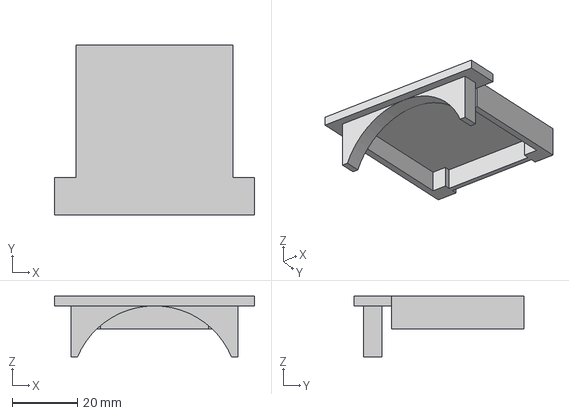
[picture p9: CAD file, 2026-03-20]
hardware/camera/CamMount/CamCap.step
61.5 x 52.4 x 18.7 mm

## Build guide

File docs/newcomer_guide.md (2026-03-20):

# Newcomer Guide

This guide is for someone opening the FPGA-Wand repository for the first time
and trying to answer one question quickly:

`What is this project, where is the real implementation, and what should I read first?`

---

## One-Sentence Summary

FPGA-Wand is a camera-based drawing system in which a PYNQ-Z1 extracts
centroid-style wand positions and streams them to a cloud service that renders,
scores, stores, and displays the result live.

If you are reading the repo as a portfolio or CV project, the right mental
model is:

`camera tracking + FPGA/PS runtime + network protocol + cloud runtime + live operator UI`

---

## What Is Final And What Is Background

The repo contains both:

- the **final adopted system**
- earlier or exploratory material that helped the project evolve

If you only want to understand the final demonstrated system, focus on:

- [../FPGA/](../FPGA/)
- [../software/](../software/)
- [architecture/overview.md](architecture/overview.md)
- [testing/system_validation_report.md](testing/system_validation_report.md)

Use the `group/` subtree mainly for report-writing, planning, and contribution
tracking rather than for the runtime architecture itself.

If your goal is only to understand the technical implementation, you can safely
ignore most of `docs/group/`.

---

## The 10-Minute Reading Path

Read these in order:

1. [../README.md](../README.md)
   the high-level system and repo map
2. [architecture/overview.md](architecture/overview.md)
   the architecture at a system level
3. [../FPGA/runtime/ps_pl_flow.md](../FPGA/runtime/ps_pl_flow.md)
   the detailed PS/PL flow on the PYNQ board
4. [../software/protocol/protocol/pynq-udp-flow.md](../software/protocol/protocol/pynq-udp-flow.md)
   how a point travels from PYNQ to the cloud
5. [../software/cloud/report/backend_system_report.md](../software/cloud/report/backend_system_report.md)
   how the backend/web/database side fits together
6. [demo/final_runbook.md](demo/final_runbook.md)
   how the final system is launched and checked in practice

If you complete those six reads, you will understand most of the final system.

---

## Choose Your Entry Point

### If you care about FPGA first

Start with:

- [../FPGA/README.md](../FPGA/README.md)
- [../FPGA/runtime/pynq_wand_brain_demo.py](../FPGA/runtime/pynq_wand_brain_demo.py)
- [../FPGA/runtime/pynq_udp_bridge.py](../FPGA/runtime/pynq_udp_bridge.py)
- [../FPGA/designs/centroid_pipeline/used_version/README.md](../FPGA/designs/centroid_pipeline/used_version/README.md)

### If you care about the backend first

Start with:

- [../software/cloud/README.md](../software/cloud/README.md)
- [../software/cloud/main.py](../software/cloud/main.py)
- [../software/cloud/backend/versions/brain_v2_scoring/src/brain/api/server.py](../software/cloud/backend/versions/brain_v2_scoring/src/brain/api/server.py)
- [../software/cloud/frontend/index.html](../software/cloud/frontend/index.html)

### If you care about the protocol first

Start with:

- [../software/protocol/README.md](../software/protocol/README.md)
- [../software/protocol/protocol/pynq-udp-brian-v1.md](../software/protocol/protocol/pynq-udp-brian-v1.md)
- [../software/protocol/protocol/brain-web_api.md](../software/protocol/protocol/brain-web_api.md)

### If you care about testing and proof first

Start with:

- [testing/system_validation_report.md](testing/system_validation_report.md)
- [testing/test-plan.md](testing/test-plan.md)
- [../software/tools/README.md](../software/tools/README.md)

---

## The Final System In Plain Terms

The final adopted system has four main stages:

1. **Physical sensing**
   the LED wand tip is seen by the camera
2. **Node-side reduction**
   the PYNQ PS and PL reduce the image to a tracked centroid point
3. **Cloud reconstruction**
   Wand Brain receives point packets, reconstructs strokes, renders images, and
   scores them
4. **User-facing operation**
   the web console shows live drawings, attempts, templates, control state, and
   leaderboards

---

## Important Distinctions

### Canonical source vs runtime artefacts

The source of truth is the code and documentation under:

- [../FPGA/](../FPGA/)
- [../software/](../software/)
- [../docs/](../docs/)

Do not confuse those with runtime artefacts such as:

- local SQLite databases
- rendered output images
- EC2 deployment copies
- temporary logs

### Adopted system vs exploratory paths

Some parts of the repository history document earlier ideas and MVP-stage work.
That material can be useful context, but it should not be confused with the
final adopted model.

For final-system understanding, prioritize:

- the centroid-based FPGA path
- the PYNQ runtime in `FPGA/runtime/`
- the Wand Brain service in `software/cloud/`

For demonstration and rerun steps, also use:

- [demo/final_runbook.md](demo/final_runbook.md)

---

## Fast Orientation By Folder

| Folder | What it is for | Read first |
| --- | --- | --- |
| [../hardware/](../hardware/) | physical build notes | [../hardware/README.md](../hardware/README.md) |
| [../FPGA/](../FPGA/) | PYNQ runtime and FPGA design | [../FPGA/README.md](../FPGA/README.md) |
| [../software/](../software/) | backend, protocols, tools | [../software/README.md](../software/README.md) |
| [group/](group/) | project-management and report-prep notes | [group/project_management_section_template.md](group/project_management_section_template.md) |

---

## If You Want To Run Something

### Cloud side

```bash
cd ../software/cloud
bash start_script.sh --install-deps
```

Then open:

```text
http://127.0.0.1:8000/
```

### PYNQ side

The main node demo is:

- [../FPGA/runtime/pynq_wand_brain_demo.py](../FPGA/runtime/pynq_wand_brain_demo.py)

---

## Best First Question To Ask

If you only have a few minutes, ask:

`What is the final adopted path from camera frame to browser view?`

The answer is spread across exactly these files:

- [../FPGA/runtime/pynq_wand_brain_demo.py](../FPGA/runtime/pynq_wand_brain_demo.py)
- [../FPGA/designs/centroid_pipeline/used_version/source/frame_centroid.v](../FPGA/designs/centroid_pipeline/used_version/source/frame_centroid.v)
- [../software/protocol/protocol/pynq-udp-flow.md](../software/protocol/protocol/pynq-udp-flow.md)
- [../software/cloud/backend/versions/brain_v2_scoring/src/brain/api/server.py](../software/cloud/backend/versions/brain_v2_scoring/src/brain/api/server.py)
- [../software/cloud/frontend/index.html](../software/cloud/frontend/index.html)

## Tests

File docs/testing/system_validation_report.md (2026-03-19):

# System Validation Report

## 1. Purpose

This report documents what was actually validated on the integrated FPGA Wand
system, what issues were discovered during integration, what fixes were applied,
and what residual limitations remain.

It complements the procedural checklist in
[`test-plan.md`](./test-plan.md). The test plan describes how to run checks. The
current report describes the observed validation outcomes for the project as it
was integrated.

## 2. System Under Validation

The validated system consisted of the following main parts:

- PYNQ node runtime:
  [`../../FPGA/runtime/pynq_wand_brain_demo.py`](../../FPGA/runtime/pynq_wand_brain_demo.py)
- PYNQ UDP and HTTP bridge:
  [`../../FPGA/runtime/pynq_udp_bridge.py`](../../FPGA/runtime/pynq_udp_bridge.py)
- used FPGA design:
  [`../../FPGA/designs/centroid_pipeline/used_version/docs/design_summary.md`](../../FPGA/designs/centroid_pipeline/used_version/docs/design_summary.md)
- cloud wrapper:
  [`../../software/cloud/main.py`](../../software/cloud/main.py)
- live Brain runtime:
  [`../../software/cloud/backend/versions/brain_v2_scoring/src/brain/api/server.py`](../../software/cloud/backend/versions/brain_v2_scoring/src/brain/api/server.py)
- frontend:
  [`../../software/cloud/frontend/index.html`](../../software/cloud/frontend/index.html)
- persistence layer:
  [`../../software/cloud/database/models.py`](../../software/cloud/database/models.py)

The validated architecture is also summarized in:

- [`../architecture/overview.md`](../architecture/overview.md)
- [`../../FPGA/runtime/ps_pl_flow.md`](../../FPGA/runtime/ps_pl_flow.md)
- [`../../software/protocol/protocol/pynq-udp-flow.md`](../../software/protocol/protocol/pynq-udp-flow.md)

## 3. Validation Strategy

Validation was performed in two complementary ways:

### 3.1 Tool-Based Validation

The repository contains synthetic and smoke-test tools used to validate the
cloud path independently of the physical board:

- [`../../software/tools/wb_connection_check.py`](../../software/tools/wb_connection_check.py)
- [`../../software/tools/full_system_smoke_test.py`](../../software/tools/full_system_smoke_test.py)

These tools were used to confirm:

- HTTP health endpoint reachability
- UDP packet acceptance
- parser and state-machine behavior
- finalized attempt creation
- image endpoint availability

### 3.2 Live Integration Validation

The most important validation happened on the integrated live system:

- real PYNQ board runtime
- real camera input
- actual FPGA centroid pipeline
- EC2-hosted Wand Brain service
- browser dashboard
- one-wand and two-wand user testing

This second category is the most significant because it validates the full
interaction between hardware, embedded runtime, network transport, backend
logic, persistence, and the operator-facing webpage.

## 4. Validation Environment

### 4.1 Board-Side

The board-side runtime validated:

- camera capture through OpenCV on PYNQ
- frame preprocessing and thresholding
- DMA transfer into the custom centroid IP
- MMIO register readback from the PL
- local sketch rendering
- UDP point transmission
- HTTP control polling and acknowledgement

### 4.2 Cloud-Side

The cloud service validated:

- UDP ingestion on port `41000`
- live HTTP service on port `8000`
- template scoring
- finalized attempt persistence
- node-control serving
- leaderboard and champion-name behavior

### 4.3 Frontend-Side

The webpage validated:

- live polling of wand status
- live image updates
- node-control form behavior
- score display
- recent attempts table
- leaderboard and claim flow
- stroke timer display

## 5. Validation Results Summary

The final integrated system achieved the following major outcomes:

| Area | Outcome |
| --- | --- |
| Cloud service startup | validated |
| UDP receive and parse | validated |
| Live plotting | validated |
| Finalized attempt rendering | validated |
| Template selection and scoring | validated |
| Database persistence | validated |
| Recent-attempt history | validated |
| Node control API and HTML panel | validated |
| Leaderboard promotion and name claim | validated |
| Stroke timer | validated |
| Single-wand end-to-end operation | validated |
| Two-wand concurrent operation | validated |

The most important project milestone was successful two-wand operation on the
same backend.

## 6. Detailed Validation Areas

## 6.1 Cloud Service Bring-Up

The cloud service was validated to:

- start successfully from the repository launcher
- serve the dashboard root page
- expose `/api/v1/health`
- listen on `8000/tcp` and `41000/udp`

This was tested both locally and on the live EC2 deployment.

### Result

Validated.

### Notes

During operation, the EC2 public IP changed at least once. The backend itself
remained functional once restarted and once the board-side `BRAIN_HOST`
configuration was updated.

## 6.2 UDP Transmission And Parser Validation

The UDP path was validated at three levels:

1. sender-side packet formation on PYNQ
2. raw socket receive on the cloud service
3. parser acceptance and conversion into live attempt state

The synthetic connectivity and smoke-test tools confirmed that:

- a generated `wb-point-v1` stroke reached the service
- the latest attempt reflected the expected `source_stroke_id`
- attempt images were generated and accessible through the HTTP image routes

### Result

Validated.

### Important Finding

The project converged on the correct semantic distinction between:

- UDP `stroke_id`
- backend-owned `attempt_id`

This prevented collisions when senders restarted or reused source stroke ids.

## 6.3 Board-Side Camera And PS/PL Pipeline

The live board validation covered:

- overlay loading
- DMA buffer allocation
- camera opening
- thresholded frame preprocessing
- custom IP MMIO stats readout
- centroid extraction
- local sketch generation

### Result

Validated, with caveats.

### Important Finding

Camera bring-up on PYNQ was not always reliable on first open. The final runtime
improved this by:

- trying more than one OpenCV backend
- performing camera warm-up reads
- failing more explicitly when no frames arrived

### Residual Caveat

The camera path can still require a restart in practice if the device state is
bad before runtime launch.

## 6.4 Live Plotting On The Dashboard

The backend and webpage were validated to show:

- template background
- live stroke updates during drawing
- finalized-attempt image after stroke completion

The live plotting path was confirmed to operate from real UDP point streams, not
from uploaded image frames.

### Result

Validated.

### Important Finding

The fixed-view live renderer was a good choice because the drawing remained
stable on screen while the stroke was still in progress.

## 6.5 Template Selection And Scoring

The template path was validated for:

- template list retrieval
- per-wand target-template selection
- finalized-attempt scoring
- score display on the webpage

Additional templates were added and served successfully, including:

- golden curve
- clover
- star

### Result

Validated.

### Important Finding

Template locking was correctly separated between:

- current active attempt, when appropriate
- next attempt, when a new selection arrived too late

That avoided ambiguity during live use.

## 6.6 Database Persistence

The database layer was validated for:

- creation and initialization
- finalized attempt storage
- recent-attempt retrieval
- champion row maintenance

The dashboard’s recent-attempt table and leaderboard view both depended on this
layer and were observed working against the live backend.

### Result

Validated.

### Important Finding

The recent-attempt view required correct ordering by finalization time rather
than only row creation time, especially when attempt rows were updated rather
than inserted.

## 6.7 Node Control Plane

The node-control system was validated in two ways:

- manual API testing against `/api/v3/node/...`
- frontend control-panel testing through the HTML interface

Validated behaviors included:

- fetching current control state
- updating control revisions
- node acknowledgement updates
- immediate pause/resume of transmission
- queued control changes for next stroke
- recalibrate and clear-sketch command dispatch

### Result

Validated.

### Important Finding

The control plane became substantially more usable once it was exposed in the
HTML dashboard rather than only through manual API calls.

## 6.8 Leaderboards And Champion Claiming

The leaderboard functionality was validated for:

- selecting the top score per template
- showing the champion table on the webpage
- allowing the current top-scoring attempt to claim a player name
- rejecting claim attempts for non-champion attempts

### Result

Validated.

### Important Finding

The correct behavior is not "any score can leave a name". Only the current top
attempt for that template can claim the champion slot.

## 6.9 Stroke Timer

The standalone timer functionality was validated in two modes:

- active stroke timing on the live page
- finalized duration display in recent attempts and latest attempt summaries

### Result

Validated.

### Important Finding

The timer worked without changing the board-side UDP format because the backend
already had enough timing information from the transmitted timestamps.

## 6.10 Single-Wand End-To-End Operation

The system was validated end to end with one active wand:

- drawing visible on the dashboard
- finalized attempt generated
- score computed
- recent-attempt history updated
- timer updated
- control path remained functional

### Result

Validated.

This was the first major integrated success condition.

## 6.11 Two-Wand Concurrent Operation

The system was then validated with two independent wands using the same backend.

The final integrated outcome was successful two-wand operation, including:

- both wands transmitting to the same backend
- the backend separating them correctly by `device_number` and `wand_id`
- live drawing and finalized attempt handling remaining functional

### Result

Validated.

### Significance

This was a major integration milestone because it demonstrated that the system
was no longer just working in a single isolated test path. It was functioning
as a multi-node interactive system.

## 7. Main Issues Found During Integration

The following issues were discovered during live integration.

## 7.1 Camera Bring-Up Instability

Observed behavior:

- camera sometimes failed to open cleanly
- startup could appear stuck at the camera step

Mitigation applied:

- more robust camera opening logic
- warm-up reads
- fallback backend attempts

## 7.2 Noisy Centroid Behavior

Observed behavior:

- unstable point vs line rendering
- tiny false starts
- occasional centroid noise

Mitigation applied:

- stronger runtime filtering and smoothing logic
- sketch-side jump rejection
- longer stroke hold behavior
- duplicate-hardware-result suppression via `frame_id`

## 7.3 Backend Attempt Identity Problems

Observed behavior:

- reused source stroke ids could collide with backend persistence
- oversized attempt-id behavior caused database issues

Mitigation applied:

- backend-owned internal `attempt_id`
- preservation of UDP `stroke_id` only as `source_stroke_id`

## 7.4 Idle Finalization Mismatch

Observed behavior:

- mismatch between board-side stroke hold timing and backend idle finalization
- possible fragmentation into tiny attempts

Mitigation applied:

- backend idle-finalize window tuning
- sender-side explicit stroke end behavior

## 7.5 Missing HTML Control Surface

Observed behavior:

- node control initially required manual API calls

Mitigation applied:

- addition of a dedicated HTML node-control panel

## 8. Residual Limitations

The final validated system still has important limitations:

- the PL centroid logic is still single-blob based rather than full
  segmentation
- active live state is not durable across backend restarts
- the webpage uses polling rather than push updates
- camera bring-up on embedded Linux is still not perfectly deterministic
- the board-side behavior depends on correct EC2 public IP configuration
- node control only affects boards running the updated control-aware runtime

These limitations do not invalidate the integrated success of the system, but
they are important to state explicitly.

## 9. Overall Assessment

The project successfully validated the complete intended interaction chain:

- camera input on PYNQ
- FPGA-assisted centroid extraction
- PS-side filtering and stroke generation
- UDP packet transport
- cloud-side receive, parse, render, and score
- persistence and leaderboard updates
- webpage monitoring and control
- successful operation with two concurrent wands

From a system-integration perspective, this is a strong result. The most
important claim that can be defended is:

The project did not only produce isolated components. It produced a working
multi-part interactive system that was validated live end to end.

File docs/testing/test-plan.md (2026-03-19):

# Test Plan

This document summarizes the practical validation strategy for the current
system.

For the outcome-oriented companion document, see
[system_validation_report.md](./system_validation_report.md).

## 1. Cloud Service Sanity Check

Start the cloud app:

```bash
cd software/cloud
bash start_script.sh --install-deps
```

Confirm:

- `GET /api/v1/health` returns `ok: true`
- `GET /api/v2/templates` returns the expected template list
- the dashboard loads on `http://127.0.0.1:8000/`

## 2. UDP Connectivity Check

Use the lightweight connection script:

```bash
python3 software/tools/wb_connection_check.py --host 127.0.0.1
```

Expected outcome:

- HTTP health succeeds
- one synthetic UDP stroke is accepted
- the latest attempt matches the transmitted `source_stroke_id`

## 3. End-to-End Smoke Test

Use the full-system smoke test:

```bash
python3 software/tools/full_system_smoke_test.py --host 127.0.0.1 --rates 25,50,100
```

Expected outcome:

- all configured strokes finalize
- live and finalized image endpoints return PNGs
- received-point counts are within the configured tolerance

## 4. PYNQ Board Validation

On each board, verify:

- camera opens reliably
- DMA/MMIO centroid reads update frame-to-frame
- the node can reach `BRAIN_HOST` over both HTTP and UDP
- control polling acknowledges revisions under `/api/v3/node/*`
- drawing appears under the correct `wand_id` and `device_number`

## 5. Frontend Validation

On the live console, verify:

- live image updates during a stroke
- recent attempts update after finalize
- template selection affects scoring target
- node-control buttons change node ack state
- leaderboard claim flow works only for the top score
- stroke timer updates during active drawing and finalizes correctly

## 6. Regression Focus Areas

Whenever the protocol or cloud state machine changes, re-check:

- `stroke_id` vs backend `attempt_id` handling
- idle finalization timing
- explicit `STROKE_END` handling
- multi-wand separation by `device_number` and `wand_id`
- database persistence after finalize
- leaderboard promotion and name-claim behavior

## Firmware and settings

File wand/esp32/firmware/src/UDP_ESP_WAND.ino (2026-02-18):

#include <Wire.h>
#include <WiFi.h>
#include <WiFiUdp.h>

// ===== Keep your working IMU pins =====
static const uint8_t SDA_PIN = 32;
static const uint8_t SCL_PIN = 33;
static const uint8_t MPU_ADDR = 0x68;
static const uint8_t LED_PIN = 25;

// ===== WiFi/UDP config (EDIT SSID/PASS ONLY) =====
const char* WIFI_SSID = "temp";
const char* WIFI_PASS = "50405049";

IPAddress PYNQ_IP(172, 27, 155, 164);   // <-- your PYNQ wlan0 IP
const uint16_t UDP_PORT = 5005;

WiFiUDP udp;

// MPU6050 registers
static const uint8_t REG_PWR_MGMT_1   = 0x6B;
static const uint8_t REG_ACCEL_XOUT_H = 0x3B;

bool writeReg(uint8_t reg, uint8_t val) {
  Wire.beginTransmission(MPU_ADDR);
  Wire.write(reg);
  Wire.write(val);
  return Wire.endTransmission() == 0;
}

bool readBytes(uint8_t reg, uint8_t *buf, size_t n) {
  Wire.beginTransmission(MPU_ADDR);
  Wire.write(reg);
  if (Wire.endTransmission(false) != 0) return false;
  if (Wire.requestFrom((int)MPU_ADDR, (int)n) != (int)n) return false;
  for (size_t i = 0; i < n; i++) buf[i] = Wire.read();
  return true;
}

static inline int16_t toInt16(uint8_t hi, uint8_t lo) {
  return (int16_t)((hi << 8) | lo);
}

static void wifiConnect() {
  WiFi.mode(WIFI_STA);
  WiFi.begin(WIFI_SSID, WIFI_PASS);

  Serial.print("WiFi connecting");
  uint32_t t0 = millis();
  while (WiFi.status() != WL_CONNECTED && millis() - t0 < 20000) {
    delay(300);
    Serial.print(".");
  }
  Serial.println();

  if (WiFi.status() == WL_CONNECTED) {
    Serial.print("WiFi OK, ESP32 IP = ");
    Serial.println(WiFi.localIP());
    Serial.print("UDP target PYNQ = ");
    Serial.print(PYNQ_IP);
    Serial.print(":");
    Serial.println(UDP_PORT);

    // optional but fine
    udp.begin(UDP_PORT);

    // one-time test packet
    udp.beginPacket(PYNQ_IP, UDP_PORT);
    udp.print("HELLO_FROM_ESP32");
    udp.endPacket();
  } else {
    Serial.println("WiFi NOT connected. (IMU still runs; UDP disabled)");
  }
}

static void udpSend(const String& msg) {
  if (WiFi.status() != WL_CONNECTED) return;

  if (!udp.beginPacket(PYNQ_IP, UDP_PORT)) {
    Serial.println("UDP beginPacket failed");
    return;
  }
  udp.print(msg);
  if (!udp.endPacket()) {
    Serial.println("UDP endPacket failed");
  }
}

void setup() {
  Serial.begin(115200);
  delay(200);

  pinMode(LED_PIN, OUTPUT);
  digitalWrite(LED_PIN, LOW);

  Wire.begin(SDA_PIN, SCL_PIN);
  Wire.setClock(100000);

  if (!writeReg(REG_PWR_MGMT_1, 0x00)) {
    Serial.println("ERROR: Cannot wake MPU6050");
    while (true) delay(1000);
  }
  delay(50);

  wifiConnect();

  Serial.println("Gesture-friendly motion gate running...");
  Serial.println("score_f state");
}

void loop() {
  // ---- read IMU ----
  uint8_t data[14];
  if (!readBytes(REG_ACCEL_XOUT_H, data, sizeof(data))) {
    Serial.println("Read error");
    delay(200);
    return;
  }

  int16_t gx = toInt16(data[8],  data[9]);
  int16_t gy = toInt16(data[10], data[11]);
  int16_t gz = toInt16(data[12], data[13]);

  // ---- motion metric ----
  uint32_t score = (uint32_t)abs(gx) + (uint32_t)abs(gy) + (uint32_t)abs(gz);

  static float score_f = 0.0f;
  const float alpha = 0.12f;
  score_f = (1.0f - alpha) * score_f + alpha * (float)score;

  const float START_TH    = 14000.0f;
  const float CONTINUE_TH = 5000.0f;
  const uint32_t STILL_MS_TO_STOP = 250;
  const uint8_t START_COUNT = 2;

  enum State { IDLE, MOVING };
  static State state = IDLE;

  static uint8_t start_hits = 0;
  static uint32_t still_since_ms = 0;

  static State last_state = IDLE;
  static uint32_t last_update_ms = 0;

  const uint32_t now = millis();

  if (state == IDLE) {
    if (score_f > START_TH) {
      if (++start_hits >= START_COUNT) {
        state = MOVING;
        start_hits = 0;
        still_since_ms = 0;
      }
    } else {
      start_hits = 0;
    }
  } else {
    if (score_f > CONTINUE_TH) {
      still_since_ms = 0;
    } else {
      if (still_since_ms == 0) still_since_ms = now;
      if (now - still_since_ms >= STILL_MS_TO_STOP) {
        state = IDLE;
        still_since_ms = 0;
      }
    }
  }

  digitalWrite(LED_PIN, state == MOVING ? HIGH : LOW);
  Serial.printf("%.0f %s\n", score_f, state == MOVING ? "MOVING" : "IDLE");

  // ---- UDP messages ----
  if (state != last_state) {
    if (state == MOVING) {
      udpSend("GESTURE_START t=" + String(now) + " score=" + String((int)score_f));
    } else {
      udpSend("GESTURE_END t=" + String(now) + " score=" + String((int)score_f));
    }
    last_state = state;
  }

  if (state == MOVING && (now - last_update_ms) >= 100) { // 10 Hz
    udpSend("GESTURE_UPDATE t=" + String(now) + " score=" + String((int)score_f));
    last_update_ms = now;
  }

  delay(20);
}

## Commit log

2026-02-14 Scaffold repo structure for ESP32 wand, FPGA stack, and cloud backend
2026-02-14 Add placeholder files to track empty directories
2026-02-18 ESP32: proof-of-concept IMU motion gating with UDP gesture events
2026-03-19 remove legacy esp32 references and stale archive content
2026-03-20 Added hardware description and test codes
    [CamCap.step, CamTestStand v2.step, wand v4.step]
2026-03-21 Add hardware documentation and design notes for camera subsystem and BOM
